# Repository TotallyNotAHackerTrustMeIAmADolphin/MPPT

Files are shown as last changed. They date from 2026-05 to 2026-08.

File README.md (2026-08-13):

# MPPT Controller - STM32F072 Firmware

A professional-grade firmware for a Maximum Power Point Tracking (MPPT) solar charge controller, optimized for the **ARM Cortex-M0** architecture. This project implements high-frequency power conversion with advanced sensing, robust safety, and optimized regulation logic.

---

## 🚀 Key Technical Features

### 1. High-Frequency PWM with Resolution Dithering
- **Frequency:** 200 kHz switching frequency for high power density.
- **Dithering:** Implements a **4-bit dithering table** (16 cycles). This effectively increases the PWM resolution from 240 steps to **3840 steps**, allowing for ultra-fine-grained voltage and current control.
- **Hardware Integration:** Managed via TIM1 with DMA-based automated duty cycle updates.

### 2. High-Performance Sensing (Ping-Pong ADC)
- **Zero-Latency DMA:** Uses circular DMA to sample 6 analog channels continuously.
- **Double Buffering:** Implements industry-standard **Ping-Pong buffering**. The CPU processes one half of the sample buffer while the DMA fills the other half, eliminating data tearing and race conditions.
- **Channels:** Input Voltage, Output Voltage, Input Current, Output Current, MOSFET Temperature, and MCU Internal Temperature.

### 3. Optimized Math Engine (Semantic Fixed-Point)
- **No FPU overhead:** Designed specifically for the STM32F0 (which lacks a hardware Floating Point Unit). All calculations use high-speed 32-bit and 64-bit integer arithmetic.
- **Unit Precision:** 
  - **Voltages:** Millivolts (`_mV`)
  - **Currents:** Milliamps (`_mA`)
  - **Power:** Microwatts (`_uW`)
  - **PWM:** Raw Dithered Ticks (`_ticks`)

### 4. Sunlight-Readable Telemetry Display
- **Hardware:** Integrated **Nokia 5110 (PCD8544)** LCD via SPI1.
- **Performance:** Non-blocking 10Hz UI refresh task decoupled from high-rate power control.
- **UI Design:** Real-time monitoring of Vin, Vout, Pout, and Operation Mode with vertical decimal alignment for high readability.

### 5. Advanced Control & Safety Logic
- **Velocity PI Regulation:** Implements a mathematically stable **Velocity PI algorithm** for Constant Voltage (CV) and Constant Current (CC) modes. This eliminates double-integration instability and provides rock-solid, ripple-free regulation.
- **Limit-Aware MPPT (P&O):** A refined Perturb & Observe algorithm with **power accumulation logic**. It accurately tracks the maximum power point on gentle slopes and intelligently "parks" the duty cycle near user limits to prevent state flapping.
- **Stabilized Global Sweep:** Slowed-down global sweep (15s duration) ensures hardware capacitors settle, providing a near-perfect MPP baseline without voltage offsets.
- **Hardware Safety Architecture:** Dedicated protection layer for the board:
  - **Over-Voltage:** 80V (Vin), 60V (Vout).
  - **Over-Current:** 20A (Input/Output).
  - **Under-Voltage:** 12.5V (Vin) floor to protect auxiliary power.
  - **Thermal:** 85°C internal limit.
  - **Reverse Flow:** Active backflow detection from battery to panel.

---

## 🛠 Hardware & Platform

### Board: openMPPT v1.1 (Custom Architecture)

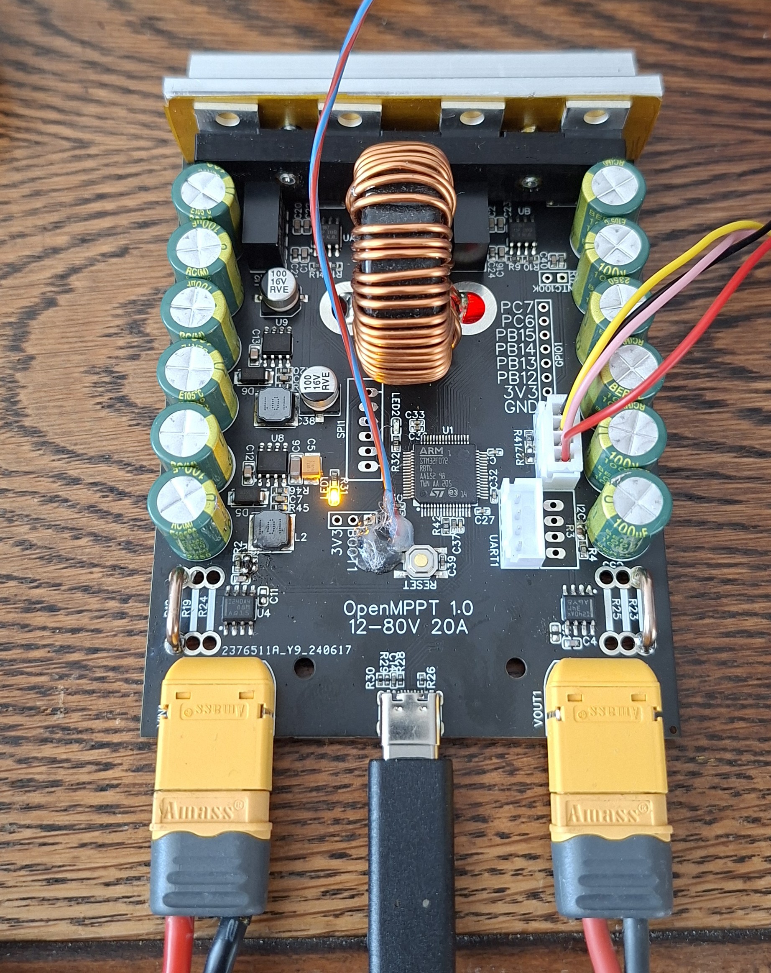
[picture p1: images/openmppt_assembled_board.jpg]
openMPPT assembled board on test bench


- **MCU:** STM32F072RBT6 (ARM Cortex-M0 @ 48MHz).
- **Topology:** 4-Switch Synchronous Non-Inverting Buck-Boost.
- **Power Stage:** Four TI **CSD19505KCS** 80V N-Channel MOSFETs driven by two Infineon **IRS21867STRPBF** gate drivers. High-side drivers are powered by isolated **B1212S-1W** DC-DC converters for continuous high-voltage operation.
- **Sensing:** Precision zero-drift **INA240A4DR** current sense amplifiers. *(Note: Footprints for isolated ACS712 sensors exist as a planned future replacement for the INA240).*
- **Auxiliary Power:** **XL7005A** wide-input buck converters providing 12V and 3.3V logic rails from panel voltage.
- **Display:** Integrated **Nokia 5110 LCD** for real-time telemetry (SPI1).
- **Framework:** STM32Cube HAL.
- **Build System:** PlatformIO using a custom `openmppt` board definition.
- **Headless Operation:** The board regulates autonomously without requiring a serial connection.

---

## 🏗 Build & Development Workflow

### Requirements
- [PlatformIO Core](https://platformio.org/)
- STM32CubeMX (optional, for peripheral reconfiguration)

### Custom Build Automation
This project uses a custom script, `setup_cubemx_env_auto.py`, which bridges the gap between STM32CubeMX and PlatformIO.
- **Automatic Constant Extraction:** The script automatically reads your PWM frequency and timer settings directly from the `MPPT.ioc` file at compile-time.
- **Link Management:** Automatically handles library linking for USB and HAL drivers.

### Commands
```bash
# Build the firmware
pio run

# Upload via Black Magic Probe (standard in platformio.ini)
pio run -t upload

# Open the serial monitor (115200 baud)
pio device monitor
```

## 📈 Auto-Tuning
The firmware supports dynamic parameter tuning over serial. A Python script is provided to automate the finding of optimal MPPT parameters (aggressiveness, step sizes, and filtering) using a hybrid machine-learning approach.

```bash
# Install dependencies
pip install pyserial

# Run the tuner (Phase 1: Random Search, Phase 2: Local Fine-Tuning)
python scripts/tune_mppt.py --port /dev/ttyACM0
```

## 📐 Hardware Design
This repository includes all necessary design files for the MPPT controller hardware in the `hardware/` directory.

- **Schematics:** SVGs and PDFs available in `hardware/schematics/`.
- **PCB Design:** Gerbers, BOM, and Pick-and-Place files located in `hardware/PCB manufacturing/`.
- **3D Files:** STEP file for case/mechanical integration in `hardware/models/`.
- **Project Files:** EasyEDA source files in `hardware/EasyEDA/` and KiCad files in `hardware/KiCad/`.

---

## 🔗 Useful Links & Resources
- **Redirect printf to USB-VCP:** [Alexey Kosinov GitHub](https://github.com/alexeykosinov/Redirect-printf-to-USB-VCP-on-STM32H7-MCU)
- **How to use C++ with STM32 HAL:** [Bare Naked Embedded](https://barenakedembedded.com/how-to-use-cpp-with-stm32-hal/)
- **STM32 ADC Multiple Channels:** [Controllerstech](https://controllerstech.com/stm32-adc-multiple-channels/)
- **Send UART over USB:** [Controllerstech](https://controllerstech.com/send-and-receive-data-to-pc-without-uart-stm32-usb-com/)

---

## 📊 Telemetry & Debugging
Real-time telemetry and configuration are provided via **USB CDC (Virtual COM Port)**.

### 🌐 Web Dashboard
The easiest way to monitor and configure the controller is via the **Web Serial Dashboard**:
👉 **[Live Dashboard](https://totallynotahackertrustmeiamadolphin.github.io/MPPT/)**

*Requires a Chrome or Edge browser. Displays data in standard units (**V**, **A**, **W**) and features a robust settings synchronization mechanism.*

### Serial Protocol
The firmware emits machine-readable **JSON packets** with descriptive fault reporting:
- `Vin_mV / Vout_mV`: Input and Output Voltages.
- `Ain_mA / Aout_mA`: Input and Output Currents.
- `state`: IDLE, SWEEPING, MPPT, CV, CC, FAULT.
- `fault_reason`: Descriptive hardware error (e.g., `INPUT_UNDERVOLTAGE`).
- `duty_x100`: PWM duty cycle as a percentage with 0.01% precision.

---

## 📏 Development Conventions

- **Variable Naming:** Always include the unit suffix in variable names (e.g., `currentIn_mA`).
- **EEPROM Safety:** The board uses a **Signature Check** (`0xABCD`) to ensure safe defaults on first flash. PWM is automatically disabled during Flash writes to prevent controller crashes.
- **Integer Math:** Perform **multiplication before division** in all scaling logic to maintain precision. Avoid `float` and `double` at all costs.

---

## 📝 License
This project is licensed under the MIT License - see the [LICENSE](LICENSE) file for details.

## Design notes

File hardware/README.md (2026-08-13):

# openMPPT Hardware Documentation

## ⚙️ Setup Requirements (per machine)
Before opening `hardware/KiCad/openMPPT_v1.3.kicad_pro`:
- **KiCad 10.0** — matches this project's file format (`generator_version "10.0"`); an older
  major version will prompt to upgrade the files.
- **Install the [`JLCPCB-Kicad-Library`](https://github.com/CDFER/JLCPCB-Kicad-Library) package**
  via KiCad's **Tools → Plugin and Content Manager**. This is the *official* PCM package — don't
  manually download/vendor a copy of it yourself, that's what causes the `KICAD8_3RD_PARTY`
  environment variable to stay unset and 3D models (switches, TVS diodes, generic passives -
  anything from the `PCM_JLCPCB` footprint library) to silently fail to render. Restart KiCad
  after installing so the variable takes effect.
- Everything else (the `easyeda2kicad`-sourced symbols/footprints/3D models for parts not on
  LCSC's basic-parts list) is already vendored in `hardware/KiCad/libraries/` and needs no setup.

## v1.3 Component Selection Summary
| Component | Part Number | Function | Rationale |
| :--- | :--- | :--- | :--- |
| Primary Buck IC | SCT2A25STER | 10V Aux Supply | High efficiency, 100V rating for 80V VIN |
| Logic Buck IC | SY8120B1ABC | 3.3V Logic Supply | Cascaded architecture for MCU safety |
| Power MOSFET | BSC030N08NS5 | Buck-Boost Stage | SMD (PG-TDSON-8-EP), 80V/100A, $R_{DS(on)}$ 3.0mΩ, $Q_g$ 76nC max |
| Bootstrap Diode | US1M | Gate Driver Supply | 1kV rating for transient protection |
| Gate-Off Diode | 1N4148W | MOSFET Turn-off | 4ns high-speed switching for low loss |
| Current Sensor | CC6937S8-3FB020 | Hall Effect Sensing | 3.3V compatible, isolated, 20A range |
| 10V TVS Diode | H12VH22U | Gate Drive Protection | 12V standoff, 6kW surge handled |
| 80V TVS Diode | 5.0SMDJ85CA | Main Rail Protection | 85V standoff, industrial 5kW capacity |

*(See `CALCULATIONS.typ` for full design justification and E24/E96 resistor value derivations.)*

## v1.1 Build Status: SUCCESS (Verified 2026-05-29)
The v1.1 PCB has been fully assembled and verified, v1.1 means the v1.0 but with some patches hand soldered to the board. However, several physical patches are required to achieve full functionality. These must be implemented in the next KiCad revision.

## 🛠 Critical Design Fixes (Implemented in v1.3)
- **Voltage Sensing**: Updated to **200k/4.7k** for 80V range.
- **Current Filter**: C10, C11 removed; moved to isolated **CC6937**.
- **Aux Power**: Replaced XL7005A with **SCT2A25/SY8120** cascaded setup.
- **Connectors**: Standardized on **Male XT60PW-M**.
- **Gate Drive**: Standardized on **5.1Ω** resistors with high-speed **1N4148W** bypass.
- **Protection**: TVS protection on the 80V main rail and 10V gate-drive rail. The 3.3V logic
  rail's originally-planned TVS (H3V3L06B, D9) was removed after datasheet verification showed
  it's an ESD-class part whose own clamping voltage exceeds the STM32's 4.0V absolute max at any
  current beyond a trivial ESD event — no purpose-built power-rail TVS clears 4.0V either (a
  physics limit of 3.3V-class parts). That rail's fault protection now rests on the SY8120B1's
  own regulation and the upstream Vin OV/UV limits already enforced in firmware.

## PCB Design Files
- **KiCad Source**: `hardware/KiCad/`
- **Production Files**: `hardware/PCB manufacturing/`
- **Vendored 3D Models/Symbols/Footprints**: `hardware/KiCad/libraries/easyeda2kicad/` (see
  "Setup Requirements" above for the one library that isn't vendored)

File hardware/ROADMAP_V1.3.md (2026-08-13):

# openMPPT Hardware v1.3 Roadmap

This document outlines the development phases for the openMPPT v1.3 hardware revision. The goal is to evolve the design from the v1.1 baseline into a high-performance, 80V/20A capable, and cost-optimized controller.

## Phase 1: Critical Stability & Bug Fixes
*Goal: Resolve all known hardware issues identified in the v1.1 bench test.*

- [x] **Voltage Sensing Correction**: Change `R1`, `R3` to **200k/4.7k** to enable correct voltage readings up to 80V. [DONE]
- [x] **Connector Standardization**: Use Male `XT60PW-M` on both `VIN` and `VOUT`. [DONE]
- [x] **Robust 10V Gate Drive**: Replace XL7005A with **SCT2A25** tuned to **10V**. [DONE]
- [x] **Cascaded 3.3V Logic Supply**: Implement **SY8120** stepping down from 10V to 3.3V. [DONE]
- [x] **Gate Drive Optimization**: Permanently change gate resistors to **5.1 Ω** with **1N4148W** turn-off diodes. [DONE]
- [ ] **Reset & Debug Pinout**: 
    - Fix the Reset button pinout.
    - Implement **10k Pull-up (SWDIO)**, **10k Pull-down (SWCLK)**, and **47Ω series resistors**.
- [x] **Filter Cleanup**: Recalculated VSense LPF to **3.47 kHz** (10nF). [DONE]

## Phase 2: UI Expansion & Peripheral Headers
*Goal: Formalize the user interface and expansion capabilities.*

- [ ] **Dedicated Nokia 5110 Header**: Standardized 8-pin header (SPI1 + DC/CE/RST + Power).
- [ ] **UI Expansion Header**: 2x Analog (Pots), 3x Digital (Encoder).
- [ ] **SWO Support**: Break out SWO to debug header.

## Phase 3: Power Scaling & Sensor Upgrades (80V/20A)
*Goal: Scale the analog front-end and power stage for higher limits.*

- [x] **Inductor Sizing**: Targeted **33µH - 47µH** with **Isat > 25A**. [SPECS DEFINED]
- [x] **Low-ESR Bulk Capacitance**: Parallel bank of 4x **330µF 100V** (Ymin LKML). [DONE]
- [x] **Hall Effect Current Sensing**: Replaced INA240 with isolated **CC6937**. [DONE]
- [ ] **20A Thermal Design**: 
    - Widen high-power traces.
    - Implement massive thermal via grid for SMD MOSFETs (if used).
- [x] **Overvoltage Protection**: Integrated **5.0SMDJ85CA** (80V) and **H12VH22U** (10V). The
      planned 3.3V TVS (**H3V3L06B**, D9) was removed after datasheet verification found it
      couldn't clear the STM32's 4.0V absolute max at any current beyond a trivial ESD event —
      see `CALCULATIONS.typ`. That rail's protection now rests on the SY8120B1's own regulation
      plus the upstream Vin OV/UV limits. [DONE]

## Phase 4: Architectural Optimization & Cost Reduction
- [x] **SMD Migration**: Transition to **BSC030N08NS5** or keeping **BRCS030N10SHRA** (TO-220) based on board space.
- [ ] **Unified Dev Header**: Combined Reset, UART, and SWD.
- [x] **Switching Frequency: 200kHz**: `TIMER_PERIOD` (`system_config.h`/`MPPT.ioc`) has
      actually computed to 200kHz since the earliest commit in this repo's history — this
      was previously undocumented, not a pending change. Component re-check done — see
      `CALCULATIONS.typ` Section 8: MOSFET switching loss roughly doubles vs. a
      hypothetical 100kHz (thermal design from this phase must land first/alongside), gate
      driver has ample margin, main inductor target halves to ~25uH. What genuinely *was*
      missing until the bootstrap-refresh firmware update: `DITHER_TABLE_SIZE` was never
      paired with the halved period (8→16 fix), and the PWM hardware map needed a
      bootstrap-cap-safe rework for v1.3's bootstrap-cap gate drive (no isolated supply).

## Phase 5: Verification & Manufacturing
- [ ] **Full DRC/ERC Audit**: Zero errors in KiCad using `kicad-cli`.
- [ ] **BOM Scrubbing**: Final LCSC part verification.
- [ ] **Generation of Production Files**: Gerbers, Drill, BOM, and CPL.

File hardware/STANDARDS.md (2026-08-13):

# openMPPT Hardware Engineering Standards

## Project Overview
This directory contains the KiCad electronic design files for the openMPPT controller.

## Core Mandates
- **Safety First**: High-power traces (VIN, VOUT, GND, VS_A, VS_B) must be sized for 20A continuous load. Standard width is **3.5mm** (assumes 2oz copper or dual-side reinforcement).
- **Component Selection**: Prioritize the **PCM-JLCPCB** library for preferred parts whenever possible.
- **Persistent Memory (Hardware Universe)**: Every new component mapping or pinout MUST be persisted into the **Hardware Universe** section immediately.
- **Mandatory Audits**: No changes shall be merged into `main` without a clean DRC/ERC report.

# Hardware Universe (Source of Truth)

## 1. MCU Pin Mapping (STM32F072RBT6)
| MCU Pin | Signal | Function | Resistors |
| :--- | :--- | :--- | :--- |
| PA13 | SWDIO | Debug Data | 10k Pull-up, 47Ω Series |
| PA14 | SWCLK | Debug Clock | 10k Pull-down, 47Ω Series |
| BOOT0 | BOOT0 | Boot Mode | 10k Pull-down |
| PC10 | LED | Heartbeat | Active-Low |

## 2. Power Stage Components (v1.3 Finalized)
| Ref | Part Number | Function | LCSC # |
| :--- | :--- | :--- | :--- |
| Q1-Q4 | **BSC030N08NS5** | Power MOSFETs | C501507 |
| U1 | **STM32F072RBT6** | MCU | C46046 |
| UA1/UB1 | **IRS21867STRPBF** | Half-Bridge Gate Driver | C52290 |
| U2/U3 | **CC6937S8-3FB020** | Isolated Current Sensor | C41421919 |
| U4 | **SCT2A25STER** | 10V Primary Aux Buck | C5124114 |
| U5 | **SY8120B1ABC** | 3.3V Logic Buck | C88474 |
| L4 | **HCZH-3218-150-M** | Buck-Boost Stage Inductor | C53699952 |
| L2 | **GXDR1207-470MT** | Aux Supply Inductor (SCT2A25/10V) | C52196367 |
| L3 | **FTC201610S4R7MBCA** | Aux Supply Inductor | C5832346 |
| C15-C18,C20-C23 | **LKML2502A331MF** | 330uF Bulk Electrolytic Cap | C443153 |
| C_IN1/C_IN2 | **TCC1210X7R225K101MT** | Input Filter Cap | C5449052 |
| D10/D11 | **5.0SMDJ85CA** | 80V Bus Protection | C42394457 |
| D8 | **H12VH22U** | 10V Gate protection | C20615799 |
| D1/D4 | **SS210** | Gate Driver Bootstrap Diode | C14996 |
| D2/D3/D5/D6 | **SS210** | Gate Discharge Diode | C14996 |
| D7 | **SS510** | Aux Buck (SCT2A25) Catch Diode | C18199171 |
| GPIO1/SPI-I2C1 | **2541WV-08P** | 8-pin Header (GPIO/SPI/I2C) | C5383116 |
| ST_LINK1/UART1 | **B4B-XH-A** | 4-pin JST-XH (ST-Link/UART) | C144395 |
| NTC1 | **PZ254V-11-02P** | 2-pin Header (NTC) | C492401 |
| H2 | **PZ254V-11-04P** | 4-pin Header | C2691448 |
| USB1 | **TYPE-C16PIN2MD** | USB-C Connector | C2765186 |
| VIN1/VOUT1 | **XT60PW-M** | Power Connector (In/Out) | C98732 |

> **L4 changed from `FC-SE2822-150M` to `HCZH-3218-150-M`** (YOUCHI, LCSC `C53699952`,
> $3.86, 88 in stock) — applied to `buck_boost.kicad_sch`, *not yet applied to the PCB*
> (its footprint uses a different pad shape/format than what's currently placed, so it
> needs a deliberate footprint swap in KiCad, not a drop-in text edit).
>
> Same 15uH as the original part, so the ripple picture is unchanged: clears the
> <100mV target at the firmware's actual 200kHz operating point (78mV) but would not
> clear it at a hypothetical 100kHz (157mV) — L4 was deliberately sized against the real
> 200kHz operating point (`TIMER_PERIOD=240` has computed to 200kHz since the earliest
> commit in this repo's history, confirmed via git log, not merely assumed). What changed
> is DCR (3.5mOhm -> 2.2mOhm, cutting conduction loss from 1.40W to 0.88W) for a $1.56
> premium over the original part.
>
> This was chosen over several alternatives considered along the way (see
> `CALCULATIONS.typ` Section 8 for the full comparison): the absolute cheapest option
> was the original part itself ($2.30); a same-inductance/near-free upgrade
> (`C54830921`, +$0.57, 89% Isat margin) was available; and a higher-margin option
> (`RSEQ32-220M`/`C37634008`, $6.26, 22uH, 304% Isat margin, 0.36W conduction loss) was
> evaluated and rejected as solving for more margin than the design needs, at a stock
> and price cost that didn't justify it for a prototype build.

> **L2 changed from `APS0650M470A` to `GXDR1207-470MT`** (FAUKU, LCSC `C52196367`,
> $0.207, 11735 in stock) — applied to both `power.kicad_sch` and the PCB. Same 47uH,
> but Isat goes from 2.62A to 4.0A, now matching `SCT2A25STER`'s own 4A peak current
> limit instead of saturating well below it, and DCR drops from 227mOhm to 90mOhm.
> Driven by a hypothetical heavier load (e.g. a fan) beyond the gate-driver/logic load
> the rail was originally sized for. Package grew from 7.7x6.6mm to 12.5x12.5mm SMD.

> **Why SS210 for both D1/D4 (bootstrap) and D2/D3/D5/D6 (gate discharge)**: D2/D3/D5/D6
> only ever see the ~10V gate-drive swing, so SS210's 100V/2A rating is more margin than
> that role strictly needs — a smaller Schottky (e.g. `B5819W`, 40V/1A, same `D_SOD-123`
> footprint already placed at those 4 spots) would be a tighter fit. Deliberately not
> doing that: one diode part number across all six positions beats a marginally-better
> fit on four of them — fewer reels at assembly, less inventory, less chance of a mix-up
> during hand work. SS210 comfortably meets every requirement of both roles (voltage,
> surge current, Schottky switching speed), just with headroom to spare on the discharge
> role.

> **D2/D3/D5/D6 footprint fixed, placement still pending**: these previously had
> `D_SOD-123` footprints on the PCB despite the schematic (correctly) specifying
> `D_SMA` for all six SS210s — now corrected to `D_SMA`, with pad-net mapping/polarity
> preserved. Since the board isn't routed yet, this surfaced the expected next step:
> `D_SOD-123` (~2.7x1.6mm) is much smaller than `D_SMA` (~5x2.6mm), so D2/D3/D5/D6
> need to be spread apart from each other and from nearby parts (R9, R10, R17, R18,
> R36-R39, UA1, UB1) during placement — normal pre-routing layout work, not a bug.

## 3. Tooling
- **KiCad CLI**: `C:\Program Files\KiCad\10.0\bin\kicad-cli.exe`
- **Vendored Library**: `hardware\KiCad\libraries\easyeda2kicad\` (16 parts not available via PCM — symbols/footprints/3D models fetched with the `easyeda2kicad` tool, registered in `sym-lib-table`/`fp-lib-table`).
- **JLCPCB Passives**: install the `CDFER/JLCPCB-Kicad-Library` package per-machine via KiCad's Plugin & Content Manager — not vendored into the repo.
- **Component swap script**: `hardware/scripts/swap_part.py` — vendors a new LCSC part and swaps it into a schematic (and optionally the PCB), handling the reformatting/UUID/net-preservation details that are easy to get wrong by hand (and have been, repeatedly). Doesn't touch STANDARDS.md/CALCULATIONS.typ or run ERC/DRC — update the docs and open KiCad to check the result yourself, same as always. See the script's own docstring for usage and its current limitations (simple passives/2-terminal parts, legacy `module`-format footprints only).

## 4. Working with Claude

Claude reads/edits the KiCad project as plain text (`.kicad_sch`/`.kicad_pcb` are S-expression
files) — it cannot open KiCad's GUI or judge layout/routing visually without a screenshot.
Workflow:

- **Visual review**: paste a screenshot of a schematic sheet, PCB layout, or 3D view. Claude
  cross-checks what's visible against this Hardware Universe table and `CALCULATIONS.typ`, and
  reads the underlying `.kicad_sch`/`.kicad_pcb` for anything a screenshot can't show precisely
  (exact net names, trace widths, footprint bindings).
- **Anti-staleness check**: before a hardware PR, or on request, Claude greps every reference
  designator in the Hardware Universe table against the actual KiCad files and reports any drift
  in footprint/value/net, rather than trusting the table from memory. Keep this table limited to
  what's genuinely hard to derive from the files (rationale, "why this part") — the KiCad project
  itself is the source of truth for raw pin/footprint data.
- **Part selection & calculations**: for new components, Claude checks datasheet specs against
  the operating envelope (MOSFET Vds/Rds(on)/Qg vs. 200kHz switching losses, inductor Isat/DCR vs.
  the 20A continuous rating, TVS clamping voltage vs. the 80V rail margin, sensor bandwidth vs. the
  ~1.5kHz control loop), checks LCSC/JLCPCB stock/package availability, and documents the
  derivation in `CALCULATIONS.typ` — not just the final part number.
- **DRC/ERC enforcement**: this is a people job. Claude does not run `kicad-cli` DRC/ERC, proactively
  or on request — board correctness review stays with the user. The "no merge without a clean
  report" mandate above is checked by the user, not by Claude.
- **Change mechanics**: hardware edits (this file, `CALCULATIONS.typ`, KiCad files) go through a
  `hardware/<name>` branch and PR, per `CLAUDE.md` — never committed straight to `main`. Example:
  `hardware/fix-resistor-values`.

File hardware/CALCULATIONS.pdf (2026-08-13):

# openMPPT Hardware Design Calculations

Theoretical basis and calculations for component selection

## 1. Power Stage Parameters

Parameter | Symbol | Value | Notes
Switching Frequency | fsw | 200 kHz | TIMER_PERIOD = 240 in system_config.h/ MPPT.ioc — confirmed via git history to have been the standing config for a year, not a future change
Maximum Input Voltage | Vin,max | 80 V | Hardware limit
Maximum Output Current | Iout,max | 20 A | Safety limit
Nominal System Voltage | Vsys | 12V / 24V / 48V | Target batteries
Gate Drive Voltage | Vdrive | 10 V | Optimized for IRS21867 thermals (v1.3)

200kHz is the actual, standing firmware config — not a planned migration. TIMER_PERIOD = 240 has computed to 200kHz since the earliest commit in this repo’s history; this was previously undocumented and this table incorrectly described it as a future 100kHz→200kHz change. What genuinely was outstanding until this PR: the PWM dither table (DITHER_TABLE_SIZE) was never paired with the halved period, so the firmware was silently running at half the duty-cycle resolution 200kHz should have — fixed by bumping DITHER_TABLE_SIZE 8→16 alongside a bootstrap-cap-safe PWM map for v1.3 (no isolated gate supply). See Section 10 for the full component re-check.

## 2. Gate Drive & Auxiliary Power Optimization (v1.3)

Primary Aux Supply (10V) - SCT2A25: Replaces the unstable 12V XL7005A with a robust 100V-rated step-down (SCT2A25).
- Output is tuned to 10V instead of 12V.
- Feedback Divider: VFB = 1.2V
- VOUT = 1.2 × (1 +
Rup

Rdown)

- Using E96 series: Rup = 110 kΩ, Rdown = 15 kΩ → VOUT = 1.2 × (1 +

110/15) = 10.0V
- Switching Frequency: Fixed at 300kHz.
- Inductor (L1
): For 10V out, a standard 33µH or 47µH inductor (e.g., 6x6mm shielded) is suitable.
- UVLO Divider: To set start at 12.5V: RUVLO_TOP = 430 kΩ, RUVLO_BOT = 47 kΩ (Both are E24).
- SW-node Freewheeling Diode: D7, SS510 (100V, 5A Schottky, C18199171) between the switch node and GND. (Previously documented here as “US1M” — never actually placed; verified against the schematic’s real net connections.)

Secondary Aux Supply (3.3V Logic) - SY8120:
- Uses a “Cascaded Buck” architecture: 10V → Tiny Sync Buck (SY8120) → 3.3V.
- Feedback Divider: VFB = 0.6V
- VOUT = 0.6 × (1 +
Rup

Rdown)

- Using E24 series: Rup = 68 kΩ, Rdown = 15 kΩ → VOUT = 0.6 × (1 +

68/15) = 3.32V ≈ 3.3V
- Switching Frequency: Fixed at 500kHz.
- Inductor (L): 4.7µH (recommended for 3.3V out).

Aux power chain verified against datasheets. SCT2A25STER: input range 5.5-100V (20V headroom over the 80V bus, comfortable margin below the 12.5V min startup voltage), VFB =1.2V±2% confirmed (validates the 110kΩ/15kΩ divider math above), 2A continuous/4A peak output vs. an estimated 150-500mA actual load (gate driver quiescent + switching current + SY8120′s input-referred draw) — current isn’t the sizing constraint, voltage range is. It’s an asynchronous buck (only the high-side switch is integrated), which is why D7 (the freewheeling diode above) is required, not optional. Datasheet is marked “Preliminary Specification, Rev.0.8” by the manufacturer — worth knowing this is pre-release.

SY8120B1ABC: verified against the actual SY8120B1 datasheet (matching LCSC C88474 exactly — the SY8120E1ABC datasheet used earlier was a same-family but different order-code stand-in, since superseded). VFB=0.6V confirmed (validates the 68kΩ/15kΩ divider math above). Input range 4.5-18V vs. the 10V it actually sees (fed from SCT2A25′s output, not the 80V bus directly) — good margin both directions. Top FET current limit (ILIM,TOP) is 2-3.6A, comfortably above L3′s 2A Isat — same category of fault-current gap as L2 had, but not upgraded: the 3.3V rail only realistically feeds the MCU/logic, nowhere near saturating L3 even with headroom for extras, unlike L2′s fan-load scenario. Decision, not an oversight.

Why D7 stays SS510, not consolidated to SS210 (unlike D1-D6, see STANDARDS.md): SCT2A25′s own 4A peak current limit exceeds SS210′s 2A continuous rating — under fault/ inrush/heavy-transient conditions the diode could see close to that 4A, which would overstress SS210 but not SS510 (5A rated). D1-D6 avoided this problem because their worst-case stress is nanosecond-scale gate-charge pulses, not sustained fault current a diode has to survive thermally.

L2 changed for the same reason D7 stays SS510: the original APS0650M470A (47µH, Isat 2.62A, DCR 227mΩ) saturates well below SCT2A25′s 4A peak limit — fine for the 150-500mA baseline load, not fine if a heavier load (e.g. a fan) gets added to the 10V rail. Replaced with GXDR1207-470MT (FAUKU, C52196367, $0.207, 11735 in stock): same 47µH, Isat 4.0A (now matching the IC’s own peak limit exactly instead of saturating below it), DCR 90mΩ (vs. 227mΩ — meaningfully lower conduction loss regardless of actual load). Package grew from 7.7×6.6mm to 12.5×12.5mm SMD.

3. Gate Driver / MOSFET Drive Synergy (IRS21867STRPBF,

## R36-R39, R9/R10/R17/R18)

Verified against the Infineon IRS21867S datasheet (full electrical table, not just the summary timing specs already checked in Section 10).

- Supply range: 6.8-20V vs. the 10V design point — comfortably mid-range, not a marginal operating point, so the propagation-delay specs (characterized at 15V) should hold closely at 10V too.
- Driver output current: IO+ (source) 5.34-6.66A, IO- (sink) 4.90-6.10A typ/max — higher than the “4.0A typ” headline spec. With 10V drive through the 2.2Ω gate resistor (R36-R39), resistor-limited peak current is 10

V
2.2Ω ≈ 4.55A — below the driver’s 5.5-6A capability, meaning the resistor is deliberately the dominant current limiter (predictable dV/dt/EMI), not the driver’s raw max rating.
- Switching speed: gate charge time ≈20-25ns (76nC max Qg
, current tapering from 4.55A toward 2.45A through the Miller plateau at Vplateau ≈ 4.6V). Combined with the driver’s 170-250ns propagation delay, total turn-on latency ≈200-275ns — about 4-5.5% of the 5000ns period at 200kHz, comfortable margin for dead-time budgeting.
- 100kΩ gate pulldown (R9/R10/R17/R18): the driver’s own UVLO drives HO/LO low when VCC/VBS is present-but-insufficient, but can’t do anything with zero power (e.g. before the 10V rail comes up during power-on sequencing) — that’s the specific gap this resistor covers. Negligible power draw during normal operation (100µA @ 10V); not intended for Miller-transient immunity during real switching (the driver’s actively-low output handles that), just a defined off-state before the driver is powered. Sane, standard value for that job.

## 4. Transient Voltage Suppression (TVS) Strategy

Primary Bus Protection (80V):
- Component: 5.0SMDJ85CA (Bidirectional, 5kW). Verified against the Hongjiacheng 5.0SMDJ series datasheet, 85V row: VRWM=85V, VBR=94.4-104V min/max, VC=137V @ IPP=36.5A (the exact 5000W spec point: 137V times 36.5A approx 5000W). Part number carries the CA suffix, which the datasheet’s own numbering note defines as bidirectional - matches the “Bidirectional” call here, though the schematic’s library symbol is filed as TVS-Uni,5.0SMDJ85CA (worth confirming in KiCad that the symbol’s polarity graphic doesn’t visually mislead a schematic reader).
- Rationale: Standoff (VRWM) of 85V ensures no leakage at 80V (IR only 5µA at VRWM, confirmed). The 5000W/10-1000µs rating (a lightning-surge waveform, appropriate for externally-coupled solar/connector transients) lets it absorb genuine surge energy without self-destructing.
- Known limitation, not a defect: this TVS cannot clamp the bus below the main MOSFETs’ rating. BSC030N08NS5′s own datasheet lists VDS absolute max as exactly 80V - zero headroom above the system’s own 80V bus limit - while this TVS’s breakdown floor is 94.4V minimum, by construction (it has to sit above the 85V standoff to avoid nuisance conduction at normal bus voltage, same underlying reason any TVS needs separation from its own breakdown voltage). No TVS standing off near 85V could protect a MOSFET with zero voltage margin; that’s a MOSFET voltage-margin decision (e.g. a 100V-rated part), not something this component can fix. This TVS’s real job is preventing catastrophic board failure (fire, ruptured caps) from an external surge
- not guaranteeing the MOSFETs stay in-spec during one.
- Placement: Immediately adjacent to VIN/VOUT XT60 connectors.

Gate Drive Protection (10V):
- Component: H12VH22U (6kW Surge). Verified against its datasheet: VRWM=12V (20% headroom over the 10V rail, IR=1µA at VRWM - confirmed low-leakage), PPP=6000W / IPP=210A at 8/20µs (matches the “6kW Surge” call), clamping voltage 13-15V @ 20A pulse -comfortably under the IRS21867′s 25V absolute max. Only exceeds that (30V) at the extreme edge of its own 200A rating, far beyond anything this rail could realistically deliver (the SCT2A25 aux buck feeding it is already current-limited to 4A, per the earlier gate-driver verification). Unlike D9′s H3V3L06B, this is a genuine surge-capable part (DFN2020-3L, 75x the pulse power), not a phone-ESD chip-scale device wearing a similar part-family name - no changes needed.
- Rationale: 12V standoff ensures invisibility at 10V rail. Protects sensitive IRS21867 drivers (25V max) from regulator failure.

Logic Protection (3.3V): removed (v1.3), D9 deleted.
- Previously H3V3L06B. Datasheet verification found it’s an ESD-class part (DFN0603-2L, IEC 61000-4-2 rated, 80W / 8A pulse rating) rather than a power-rail transient absorber, and its own clamping-voltage table (3.5-6V at 1A, up to 10V at its rated 8A) exceeds the STM32′s 4.0V absolute max (confirmed against the STM32F072 datasheet, Table 21: Voltage characteristics) at any current beyond a trivial ESD-level event - it could not do the job its own rationale claimed.
- Checked purpose-built power-rail TVS alternatives before removing it: Nexperia PTVS3V3S1UR (400W) clamps at 8V, Littelfuse SMF3.3 (200-1200W) clamps at 6.8V. Neither clears 4.0V either -this is a physics limit of 3.3V-class TVS diodes (they need real separation from their own breakdown voltage to keep leakage low at rest), not a part-selection mistake. No drop-in replacement exists that actually satisfies the original “keeps the rail under 4.0V” rationale.
- Decision: remove D9 rather than keep a component that can’t do its stated job. The 3.3V rail’s fault protection now rests on the SY8120B1′s own regulation and the upstream Vin OV/UV limits already enforced in system_config.h, not an additional clamp on this rail.

## 5. Inductor Sizing (Main Power Stage)

Targeting a peak-to-peak ripple current (ΔIL) of 20% of Iout,max (4.0 A).

Buck Mode Worst-Case: (50% Duty Cycle, e.g., 80V in, 40V out)

Lbuck =

Vout × (Vin − Vout)
ΔIL × fsw × Vin

At fsw = 100kHz: Lbuck =

40×40
4.0×100000×80 = ∗ 50.0µH ∗

v1.3 Component Selection: Target inductor size: 33 µH to 47 µH.
- CRITICAL: Saturation Current (Isat) MUST be > 25A. Using a lower Isat (like 11A) will cause magnetic collapse and MOSFET destruction.

## 6. Bulk Capacitor Selection

Targeting an output voltage ripple (ΔVout) of < 100mV.

ESRmax =

ΔVout
ΔIL

=

0.1V
4.0A

= ∗ 25mΩ ∗

v1.3 Capacitor Strategy:
- Use 4x 330µF 100V Low-ESR Electrolytic (Ymin LKML2502A331MF, C443153) in parallel, per bulk bank (input and output each get their own 4-cap bank, C15-C18 / C20-C23 in the schematic).
- Verified against the Ymin LKM series datasheet (not assumed): the part number itself decodes to series LKM + diameter code L (12.5mm) + height code 250 (25mm) + voltage code 2A (100V) + capacitance code 331 (330µF) + M (±20%) - exactly LKML2502A331MF. The series’ standard-item table confirms the 12.5×25mm/100V/330µF row directly: ESR = 47mΩ max and ripple current = 2.14A rms, both specified at 100kHz/25°C - the exact figures this section already assumed.
- Total Bank ESR: 47mΩ
4 = ∗ 11.75mΩ ∗ (Passes the 25mΩ limit with 53% margin).
- Total Ripple Capacity: 2.14 A × 4 = ∗ 8.56 A ∗ per bank. The actual RMS ripple current a bulk cap bank sees is ≈

ΔIL
2

√
3

≈ 1.15 A - the 8.56A rating is headroom against that, not a comparison to the 20A DC bus current.
- Voltage margin: 100V rating on an 80V max bus is a 20% derating margin - inside the range electrolytics are normally run at continuously, though tighter than the 25-30% some DC-link guidance recommends.
- The series’ own ripple-current frequency correction table (0.40, 0.50, 0.80, 0.90, 1.00 at 50Hz, 120Hz, 1kHz, 10-50kHz, 100kHz respectively) confirms the rated ripple current is already anchored at its ceiling by 100kHz, with no published derating beyond that - supporting the “frequency-independent” call in the Section 10 re-check below.
- Cost pass (checked, not adopted): cheaper and SMD alternatives were surveyed against this same spec. Nothing beats LKML2502A331MF on cost, ESR, ripple, and life simultaneously - every cheaper part found trades away life rating (10000h to 5000h) to hit its price point. The one genuine free improvement: 3 caps per bank would already suffice -

47mΩ
3 ≈ 15.7mΩ still clears
the 25mΩ limit with 37% margin, and ripple capacity (2.14 A × 3 ≈ 6.4 A) stays far above the 1.15A actual RMS need. Staying at 4x for the extra ESR/ ripple headroom and to keep it symmetric with the input/output bank layout - not a requirement, a margin choice.

## 7. Voltage Divider & ADC Scaling

Voltage Sensing LPF (v1.3 Optimized):
- Rtop = 200 kΩ, Rbottom = 4.7 kΩ.
- Rth ≈ 4.59 kΩ
- Cfilter = 10 nF

- fc =
2π×4590×10×10

−9 ≈ 3.47 kHz
- Evaluation: Balanced for high-speed tracking and noise rejection.

## 8. Current Sense (CC6937S8-3FB020, U2/U3)

Verified against the CrossChip CC6937 datasheet (not a name-convention guess).

- Type: Isolated Hall Effect, 3750VRMS isolation (pins 1-4 to 5-8) — 47x margin over the 80V bus.
- Sensitivity: 66mV/A (confirmed from the ordering table for the −3FB020 variant).
- Supply: VCC 3.0-3.3V nominal — the “3” in “3FB” denotes the 3.3V-supply series, matching the system’s logic rail exactly.
- Range: ±20A. Zero-current output VOUTQ ≈ 1.65V (VCC/2, confirmed), full scale swings to ≈ 0.33-2.97V — centered and within a 3.3V ADC’s linear range.
- Response time: 1.5µs (10-90% step) — well under one 200kHz switching period (5µs), adequate for fast overcurrent/backflow trip.
- Bandwidth: 230kHz −3dB, 150x margin over the 1.5kHz control loop sample rate. Margin over switching frequency shrinks from 2.3x (100kHz) to 1.15x (200kHz) at full power — not a concern for this design (average sensing + fast-trip response time, not raw bandwidth, govern both use cases here), but worth knowing if the sensor’s role ever changes to reconstructing switching-ripple waveforms directly.
- Insertion loss: 0.5mΩ internal conductor resistance — negligible, and the reason this replaced the INA240+shunt approach from v1.1 (per ROADMAP_V1.3.md).
- Decoupling: 1nF VREF-to-GND (matches the datasheet’s own CREF=1nF test condition; confirmed in the schematic as C10/C26) and a separate 100nF (0.1µF) VCC bypass (confirmed as C12 near U2). Also 1nF at VOUT per the datasheet’s COUT=1nF condition.

## 9. Factory Calibration Defaults (settings.c)

Calibration_t needs sane defaults so a fresh board reads roughly-correct values before real calibration is run (per the EEPROM signature-check pattern in CLAUDE.md). Derived from the hardware specs above, not bench-measured — replaces stale v1.1-era defaults that were still assuming the pre-v1.3 divider ratio ( 3.3x off from the actual 200k/4.7k parts).

Voltage (Vin/Vout share identical R5/R6 and R13/R14 200k/4.7k dividers):

raw = Vreal,mV ×

4.7
204.7

÷ 3300mV × 4096

(12-bit ADC, VDDA ≈ 3300mV.) Gives 285 @ 10V, 855 @ 30V — used as the Low/High calibration pair for both channels.

Current (Iin/Iout share identical CC6937S8-3FB020, 66mV/A, VOUTQ = VCC/2 = 1.65V @ 0A):

raw = Vadc,mV ÷ 3300mV × 4096

Gives 2048 @ 0A exactly (the datasheet’s own zero-current condition) - this point is polarity-independent, always correct regardless of sign. The 10A high point (1229 raw) assumes higher current reads as a lower raw value, matching the slope direction of the previous (bench-measured, v1.1-era) defaults for this field - not independently verified against the physical board. The polarity depends on which way current actually flows through U2/U3 relative to their pin 1-4/5-8 orientation, which isn’t something derivable from the datasheet alone. Bench-verify the sign before trusting these current defaults in the field; if it’s backwards, the fix is recomputing the high point with the opposite sign (2048 + 10000×0.066/3300×4096 ≈ 2867 instead of 2048 − … ≈ 1229) - not simply swapping the two existing numbers, which would produce a different wrong pair, not the correct one.

## 10. 200kHz Operation: Component Verification

This section verifies the selected parts against the switching frequency the firmware actually runs at (200kHz, confirmed via git history — not a future migration), using values pulled directly from the vendored datasheets (not assumed). Comparisons against 100kHz are kept below for reference/ context, not because 100kHz is a live alternative. This is the check called for by the STANDARDS.md “Part selection & calculations” mandate for the ROADMAP_V1.3.md Phase 4 checklist item.

### 10.1. Main Switching MOSFETs (Q1-Q4, BSC030N08NS5, C501507)

Source: Infineon BSC030N08NS5 datasheet, Rev. 2.3, 2019-10-31.

Parameter | Value | Condition
RDS(on) | 2.6 mΩ typ / 3.0 mΩ max | VGS=10V, ID=50A
Qg (total gate charge) | 61 nC typ / 76 nC max | VDD=40V, ID=50A, VGS=0→10V
tr (turn-on rise) | 12 ns typ | VDD=40V, VGS=10V, ID=50A, RG,ext =3Ω
tf (turn-off fall) | 13 ns typ | same
Coss | 700 pF typ / 910 pF max | VDS=40V, f=1MHz
Rth JA (PCB only, no heatsink) | 50 K/W | 6 cm² copper, 1-layer, natural convection
Tj,max | 150 °C | —

Conduction loss (frequency-independent):

Pcond = I

2
rms × RDS(on),max = 20

2 × 0.0030 ≈ ∗ 1.2 W ∗

Switching loss (linear-approximation model, worst case VDS = 80V, ID = 20A):

Psw =

1
2

× VDS × ID × (tr + tf

) × fsw

| 100 kHz (reference only) | 200 kHz (actual)
Psw per hard-switched MOSFET | 2.0 W | 4.0 W
Pcond per MOSFET | 1.2 W | 1.2 W (unchanged)
Total est. loss | ≈3.2 W | ≈5.2 W

Thermal flag — live at the firmware’s actual 200kHz, not hypothetical. With PCB-only cooling (Rth JA=50 K/W, no heatsink/thermal vias), the datasheet’s own max package dissipation at TA=25°C is Ptot =

150−25
50 = ∗ 2.5 W ∗ — already below the ≈3.2W estimate at 100kHz, let alone the ≈5.2W the board actually sees at its real 200kHz operating point. This assumes worst-case VDS/ID coincidence and a simplified switching-loss model (real loss depends on which of Q1-Q4 is hard-switched vs. synchronous-rectifying in the actual buck-boost topology, and gate resistance/drive strength affect tr/tf
| in-circuit). This is exactly what ROADMAP_V1.3.md
Phase 3′s open item (“20A Thermal Design: widen high-power traces, implement massive thermal via grid”) already anticipates — that item should land before or alongside the 200kHz switch, not after. The bottom-side Rth JC path (0.5-0.9 K/W typ/max) is dramatically better than the PCB-only path and is what a proper thermal via array would unlock.

Gate drive loss (in the driver/gate resistor, not the MOSFET junction — informational):

Pgate = Qg × VGS × fsw = 76 × 10

| −9 × 10 × fsw

At 100kHz: 76mW/MOSFET. At 200kHz: 152mW/MOSFET. Not a concern for the driver IC’s thermal budget either way.

Cost pass (checked, not adopted): a cheaper 100V candidate, Huixin H80N10FB (C49823472), was evaluated to replace BSC030N08NS5 - similar RDS(on) (3.0/3.6mΩ) and Qg
(67/100.5nC) made it look
like a clean upgrade at first pass. It was not adopted: its datasheet lists tr=92.0ns / tf=82.4ns typ (comparable test conditions to the table above) - 6-7x slower than BSC030N08NS5′s 12/13ns, despite the similar Qg

. Re-running the switching-loss formula above with those numbers gives ≈ 14 W per MOSFET at 100kHz alone (vs. the 2.5W PCB-only thermal ceiling this section already flags), instead of the expected 2.0W. Lesson for future MOSFET swaps on this board: RDS(on) and Qg alone don’t predict switching speed - Qg
is gate charge, not switching time, and depends heavily on a part’s internal gate resistance and Miller-plateau behavior. Always check tr/tf

(or td(on)/td(off))
against a comparable test condition before treating a swap as electrically equivalent.

### 10.2. Gate Driver (IRS21867STRPBF, C52290)

Source: Infineon IRS21867S datasheet v01.00.

Parameter | Value | Condition
ton / toff propagation delay | 170 ns typ / 250 ns max | VCC = VBS=15V, CL=1000pF
MT (delay matching, |ton − toff|) | 35 ns max | —
tr / tf (driver output) | 22/18 ns typ, 38/30 ns max | —
Output source/sink current | 4.0 A typ | —

At 200kHz the switching period is 5.0µs vs. 10µs at 100kHz. The 170-250ns propagation delay grows from 2.5% to 5% of the period — worth including explicitly in dead-time budgeting, but well within normal margins; not a hard blocker on 200kHz operation. Output drive current (4.0A) is unchanged and still comfortably swings Qg=76nC in the tens-of-ns range required. No datasheet-stated
maximum switching frequency applies here.

### 10.3. Main Inductor (L4)

Re-deriving Section 5′s formula at 200kHz:

Lbuck(200kHz) =

40 × 40
4.0 × 200000 × 80

= ∗ 25.0µH ∗

This halves the 100kHz target (50µH → 25µH). The originally-placed part, FC-SE2822-150M (C46553544, verified via datasheet, not the name-convention guess this section originally used): 15µH ±20%, Isat 30.5A, rated 30A, DCR 3.5mΩ, 28x23mm THT, $2.30 / 407 in stock.

| 100kHz (reference only) | 200kHz (actual firmware)
Ripple current ΔIL | 13.3A | 6.67A
Peak current / Isat margin | 26.7A / 14% | 23.3A / 31%
Output ripple ΔVout (bank ESR 11.75mΩ) | 157mV — 57% over the 100mV target | 78mV ✓
Conduction loss (I out × DCR) 2 | 1.40W | 1.40W (freq-independent)

L4 only meets the ripple spec at 200kHz — a real, accepted dependency, not a bug. It was deliberately sized against the firmware’s actual 200kHz operating point (confirmed via git history, not merely assumed), specifically to avoid the “humongous” 50µH part a 100kHz target would otherwise require. This is not something to fix by re-checking values; it’s a documented design decision.

Candidate replacements evaluated — two rounds. First pass (22-30µH / Isat≥30A, filtered to in-stock — 19 of 21 candidates found were out of stock and excluded) optimized purely for margin and found C37634008 (RSEQ32-220M, Ruishen): 22µH, Isat 90A, DCR 0.9mΩ, $6.26/26 in stock — 304% Isat margin and 0.36W conduction loss at 200kHz, a huge improvement. Rejected after a second look: this compared candidates against each other without ever checking the original part’s own price/stock ($2.30, 407 in stock) — a 2.7x price and 15x stock gap that makes “maximum margin” the wrong optimization target for a prototype build.

Second pass widened the inductance range (15-33µH) and weighed cost/stock properly:

FC-SE2822-150M (orig.) | C54830921 | HCZH-3218-150-M (chosen) | C37634008
Manufacturer FANGCHENG | Coilank | YOUCHI | Ruishen
Stock / 407 / $2.30 Price | 69 / $2.87 | 88 / $3.86 | 26 / $6.26
L / 15µH / 30.5A / 3.5mΩ Isat / DCR | 15µH / 44A / 3.0mΩ | 15µH / 30A / 2.2mΩ | 22µH / 90A / 0.9mΩ
Package THT 28x23mm | THT 33.5x28mm | THT 33.5x28mm | THT 33x31.5mm
200kHz 78mV / 31% ripple / Isat margin | 78mV / 89% | 78mV / 29% | 53.4mV / 304%
200kHz 1.40W conduction loss | 1.20W | 0.88W | 0.36W

C54830921 is the best pure value play (+$0.57 for 89% Isat margin, same ripple). HCZH-3218-150-M was chosen instead for its lower DCR (0.88W conduction loss, a real efficiency win) at a still-modest $1.56 premium over the original part — a deliberate prototype-stage trade-off (moderate cost increase for a meaningful efficiency gain, not chasing the maximum-margin C37634008 pick, which cost 2.7x more for headroom this design doesn’t need).

Chosen: HCZH-3218-150-M (YOUCHI, C53699952). Applied to buck_boost.kicad_sch; PCB footprint not yet updated — see STANDARDS.md’s L4 note for status.

### 10.4. Summary

ItemVerdict at 200kHz
MOSFETs (BSC030N08NS5) | Electrically fine (Vds/Rds(on)/Qg headroom unchanged), but switching loss ≈doubles — thermal design (ROADMAP Phase 3) must land first
Gate driver (IRS21867STRPBF) | No concern — propagation delay and drive current have ample margin
Main inductor (L4) | Replacement chosen: HCZH-3218-150-M (C53699952) — clears ripple target at 200kHz, DCR cut from 3.5mΩ to 2.2mΩ (0.88W conduction loss), for a modest $1.56 premium over the original part
Bulk caps / | Frequency-independent, no re-check needed

ItemVerdict at 200kHz
TVS / voltage sensing

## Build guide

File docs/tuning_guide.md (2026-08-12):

# MPPT Tuning & Architecture Guide

## Control Architecture: The Unified Min-Selector
The system has moved away from discrete state-based PID loops. It now uses a **Unified Override Control** model:
1.  **Multiple Deltas**: Every control objective (MPPT, Output CV, Output CC, Input UV, etc.) calculates its own desired change ($\Delta$) in duty cycle.
2.  **Min-Selector**: The controller selects the **minimum** $\Delta$ among all active constraints.
    *   Example: If MPPT wants to increase duty (+10) but Output CV needs to decrease it to stay at 14.4V (-5), the controller picks -5.
3.  **Velocity PI**: The selected $\Delta$ is accumulated into a 64-bit high-resolution integrator, which is then applied to the hardware PWM.

## Telemetry States
The `state` string in the telemetry provides granular feedback on which limit is currently "winning" the selector:
- `MPPT`: No limits hit, MPPT (or the fixed setpoint in CV/CC/PSU modes) is in control.
- `CV`: Output Voltage limit is active (Battery Full).
- `CC`: Output Current limit is active.
- `BROWNOUT`: Input Voltage is dropping below the soft-floor (`vInMin_mV`).
- `REV_V`: Input Voltage is hitting the upper limit in reverse flow (`vInMax_mV`).
- `REV_I_IN`: Reverse current limit is active on the input-side sensor (`iInMin_mA` - protects the source/battery being backfed).
- `REV_I_OUT`: Reverse current limit is active on the output-side sensor (`iOutMin_mA`).

## Control Gains
- `GAIN_KP`: Proportional gain. Currently tuned to **5** for stable transitions on openMPPT v1.1 hardware.
- `GAIN_KI`: Integral gain. Currently **2**.
- `SOFT_LIMIT_HOLD_TIME_MS`: Set to **100ms** to prevent dashboard flickering when bouncing on a limit.

## Lab Setup (Simulated Solar Panel)
To simulate a solar panel curve using a standard 60V/5A Lab PSU:
1.  **Source Side**: Connect the PSU in series with a **4.7 Ω (100W+)** resistor.
2.  **Load Side**: Connect the MPPT output to a **2.2 Ω (200W+)** resistor or a 12V battery.
3.  **Cooling**: Ensure resistors have active cooling.

## Running the Tuning Session
1.  **Environment**: Ensure `pyserial` is installed (`pip install pyserial`).
2.  **Execution**:
    ```bash
    python scripts/tune_mppt.py --port /dev/ttyACM0 --random-iters 15 --fine-iters 10
    ```
3.  **Algorithm**:
    *   **Phase 1 (Random Search)**: Explores step sizes and EMA filtering.
    *   **Phase 2 (Fine Tuning)**: Optimizes around the best local candidate.

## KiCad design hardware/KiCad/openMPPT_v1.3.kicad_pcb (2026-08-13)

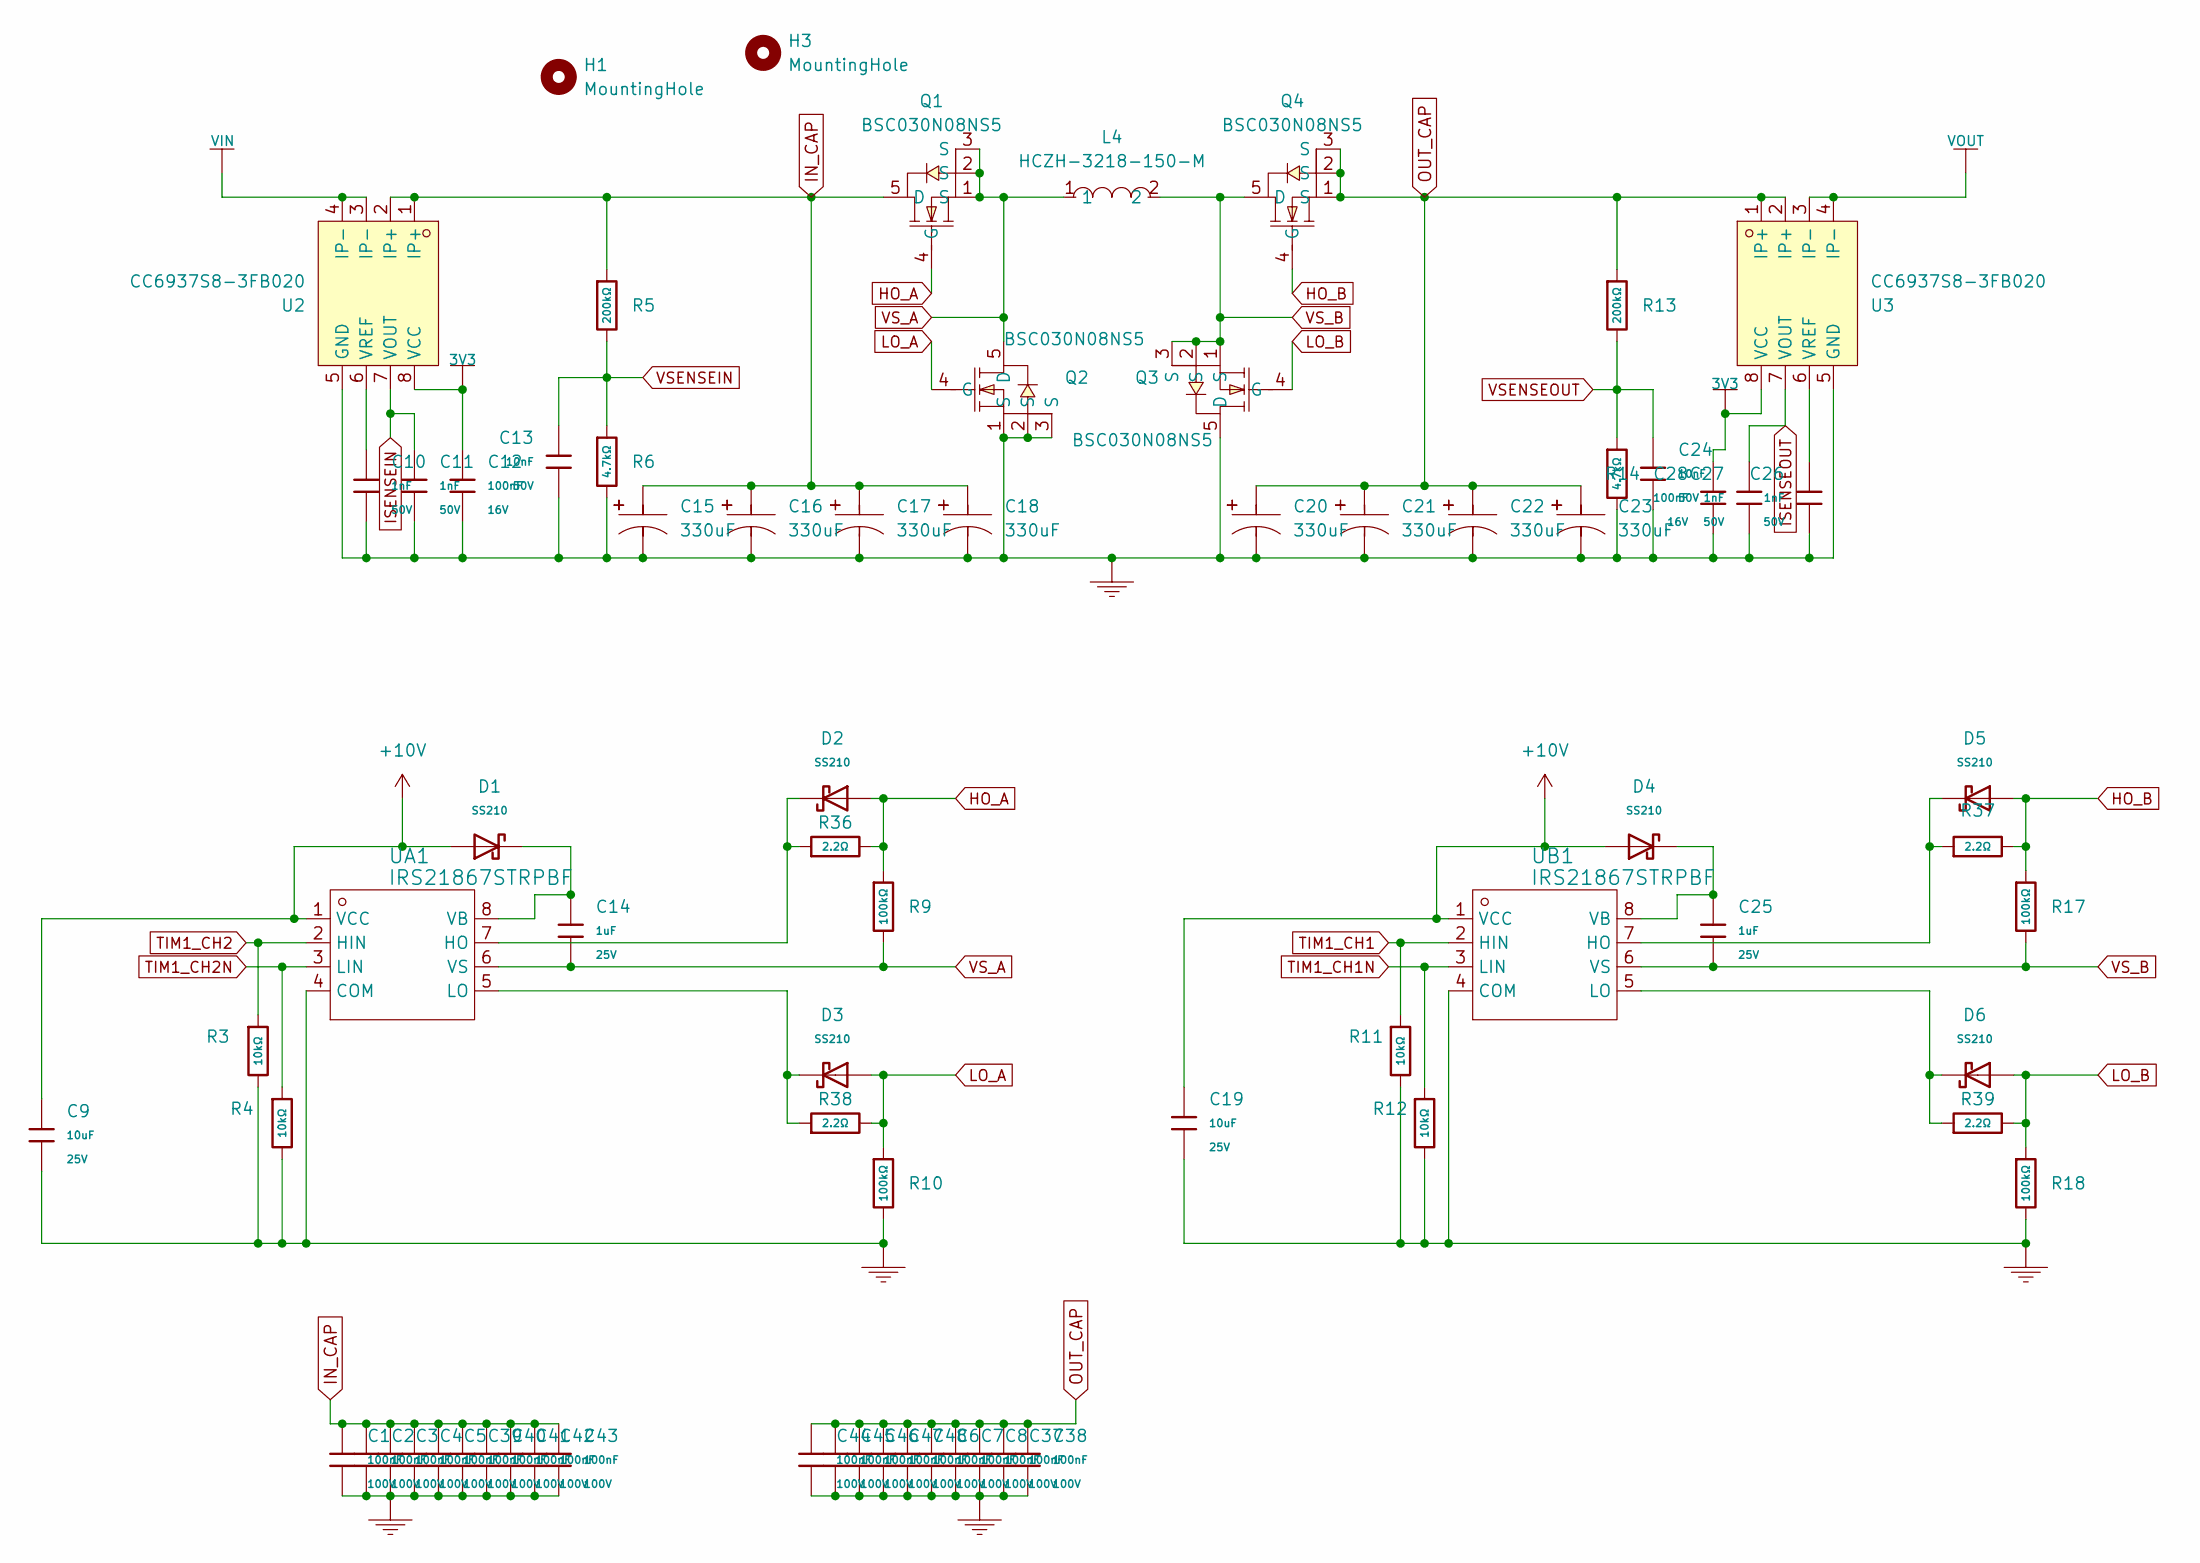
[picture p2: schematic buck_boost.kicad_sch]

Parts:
C1, C2, C3, C4, C5, C6, C7, C8, C37, C38, C39, C40, C41, C42, C43, C44, C45, C46, C47, C48: 100nF; C_0805; Voltage Rated 100V; Tolerance ±10%; Part CL21B104KCFNNNE; LCSC C28233
C9, C19: 10uF; C_0603; Voltage Rated 25V; Tolerance ±20%; Part CL10A106MA8NRNC; LCSC C96446
C10, C11, C26, C27: 1nF; C_0402; Voltage Rated 50V; Tolerance ±10%; Part 0402B102K500NT; LCSC C1523
C12, C28: 100nF; C_0402; Voltage Rated 16V; Tolerance ±10%; Part CL05B104KO5NNNC; LCSC C1525
C13, C24: 10nF; C_0402; Voltage Rated 50V; Tolerance ±10%; Part CL05B103KB5NNNC; LCSC C15195
C14, C25: 1uF; C_0402; Voltage Rated 25V; Tolerance ±10%; Part CL05A105KA5NQNC; LCSC C52923
C15, C16, C17, C18, C20, C21, C22, C23: 330uF; CAP-TH_BD12.5-P5.00-D0.6-FD; MPN LKML2502A331MF; LCSC Part C443153
D1, D2, D3, D4, D5, D6: SS210; D_SMA; Forward Voltage (Vf@If) 850mV@2A; Reverse Voltage (Vr) 100V; Part SS210; LCSC C14996
H1, H3: MountingHole; MountingHole_3.2mm_M3_DIN965
L4: HCZH-3218-150-M; IND-TH_L33.5-W23.0-P12.00_HCZH-3218; MPN HCZH-3218-150-M; LCSC Part C53699952
Q1, Q2, Q3, Q4: BSC030N08NS5; PG-TDSON-8_L5.0-W6.0-P1.27-BL-EP; MPN BSC030N08NS5; LCSC Part C501507
R3, R4, R11, R12: 10kΩ; R_0402; Overload Voltage (Max) 50V; Tolerance ±1%; Part 0402WGF1002TCE; LCSC C25744
R5, R13: 200kΩ; R_0603; Overload Voltage (Max) 75V; Tolerance ±1%; Part 0603WAF2003T5E; LCSC C25811
R6, R14: 4.7kΩ; R_0603; Overload Voltage (Max) 75V; Tolerance ±1%; Part 0603WAF4701T5E; LCSC C23162
R9, R10, R17, R18: 100kΩ; R_0603; Overload Voltage (Max) 75V; Tolerance ±1%; Part 0603WAF1003T5E; LCSC C25803
R36, R37, R38, R39: 2.2Ω; R_0603; Overload Voltage (Max) 75V; Tolerance ±1%; Part 0603WAF220KT5E; LCSC C22939
U2, U3: CC6937S8-3FB020; SOP-8_L4.9-W3.9-P1.27-LS6.0-BL; MPN CC6937S8-3FB020; LCSC Part C41421919
UA1: IRS21867STRPBF; SOIC-8_L5.0-W4.0-P1.27-LS6.0-BL; Manufacturer Part IRS21867STRPBF
UB1: IRS21867STRPBF; SOIC-8_L5.0-W4.0-P1.27-LS6.0-BL; Manufacturer Part IRS21867STRPBF

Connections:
3V3: C12.1, C28.1, U2.8 (VCC), U3.8 (VCC); also elsewhere on the board
+10V: C9.1, C19.1, D1.2, D4.2, UA1.1 (VCC), UB1.1 (VCC); also elsewhere on the board
GND: C1.2, C2.2, C3.2, C4.2, C5.2, C6.2, C7.2, C8.2, C9.2, C10.2, C11.2, C12.2, C13.2, C15.2 (-), C16.2 (-), C17.2 (-), C18.2 (-), C19.2, C20.2 (-), C21.2 (-), C22.2 (-), C23.2 (-), C24.2, C26.2, C27.2, C28.2, C37.2, C38.2, C39.2, C40.2, C41.2, C42.2, C43.2, C44.2, C45.2, C46.2, C47.2, C48.2, Q2.1 (S), Q2.2 (S), Q2.3 (S), Q3.5 (D), R3.2, R4.2, R6.2, R10.2, R11.2, R12.2, R14.2, R18.2, U2.5 (GND), U3.5 (GND), UA1.4 (COM), UB1.4 (COM); also elsewhere on the board
HO_A: D2.2, Q1.4 (G), R9.1, R36.2
HO_B: D5.2, Q4.4 (G), R17.1, R37.2
IN_CAP: C1.1, C2.1, C3.1, C4.1, C5.1, C15.1 (+), C16.1 (+), C17.1 (+), C18.1 (+), C39.1, C40.1, C41.1, C42.1, C43.1, Q1.5 (D), R5.1, U2.1 (IP+), U2.2 (IP+)
ISENSEIN: C11.1, U2.7 (VOUT); also elsewhere on the board
ISENSEOUT: C27.1, U3.7 (VOUT); also elsewhere on the board
LO_A: D3.2, Q2.4 (G), R10.1, R38.2
LO_B: D6.2, Q3.4 (G), R18.1, R39.2
unnamed: C10.1, U2.6 (VREF)
unnamed: C26.1, U3.6 (VREF)
unnamed: D2.1, R36.1, UA1.7 (HO)
unnamed: D3.1, R38.1, UA1.5 (LO)
unnamed: C14.1, D1.1, UA1.8 (VB)
unnamed: D5.1, R37.1, UB1.7 (HO)
unnamed: D6.1, R39.1, UB1.5 (LO)
unnamed: C25.1, D4.1, UB1.8 (VB)
OUT_CAP: C6.1, C7.1, C8.1, C20.1 (+), C21.1 (+), C22.1 (+), C23.1 (+), C37.1, C38.1, C44.1, C45.1, C46.1, C47.1, C48.1, Q4.1 (S), Q4.2 (S), Q4.3 (S), R13.1, U3.1 (IP+), U3.2 (IP+)
TIM1_CH1: R11.1, UB1.2 (HIN); also elsewhere on the board
TIM1_CH1N: R12.1, UB1.3 (LIN); also elsewhere on the board
TIM1_CH2: R3.1, UA1.2 (HIN); also elsewhere on the board
TIM1_CH2N: R4.1, UA1.3 (LIN); also elsewhere on the board
VIN: U2.3 (IP-), U2.4 (IP-); also elsewhere on the board
VOUT: U3.3 (IP-), U3.4 (IP-); also elsewhere on the board
VSENSEIN: C13.1, R5.2, R6.1; also elsewhere on the board
VSENSEOUT: C24.1, R13.2, R14.1; also elsewhere on the board
VS_A: C14.2, L4.1, Q1.1 (S), Q1.2 (S), Q1.3 (S), Q2.5 (D), R9.2, UA1.6 (VS)
VS_B: C25.2, L4.2, Q3.1 (S), Q3.2 (S), Q3.3 (S), Q4.5 (D), R17.2, UB1.6 (VS)

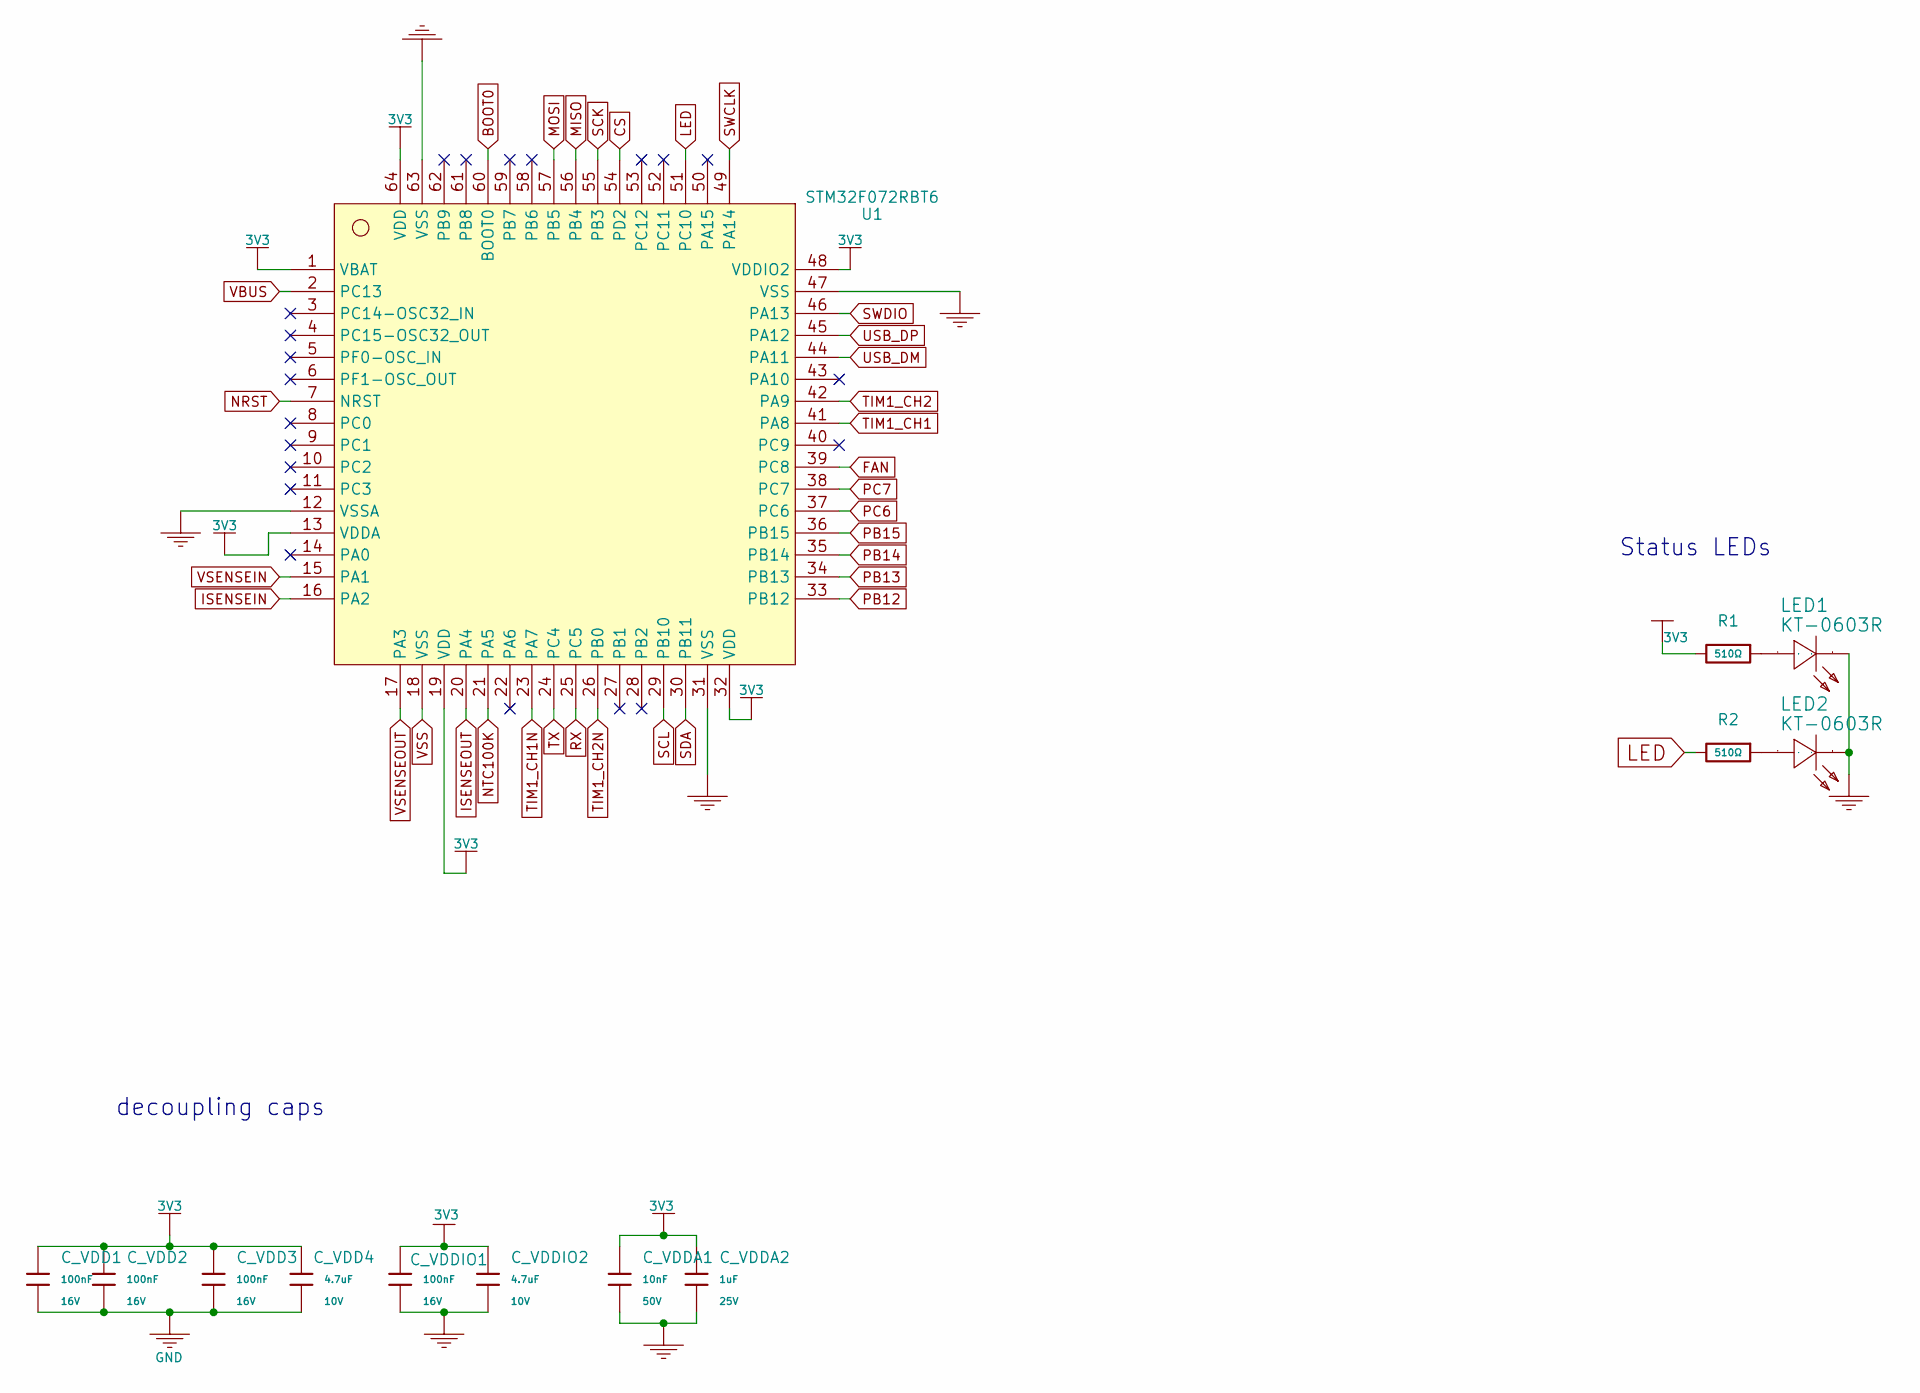
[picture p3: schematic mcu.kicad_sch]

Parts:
C_VDD1, C_VDD2, C_VDD3: 100nF; C_0402; Voltage Rated 16V; Tolerance ±10%; Part CL05B104KO5NNNC; LCSC C1525
C_VDD4: 4.7uF; C_0402; Voltage Rated 10V; Tolerance ±20%; Part CL05A475MP5NRNC; LCSC C23733
C_VDDA1: 10nF; C_0402; Voltage Rated 50V; Tolerance ±10%; Part CL05B103KB5NNNC; LCSC C15195
C_VDDA2: 1uF; C_0402; Voltage Rated 25V; Tolerance ±10%; Part CL05A105KA5NQNC; LCSC C52923
C_VDDIO1: 100nF; C_0402; Voltage Rated 16V; Tolerance ±10%; Part CL05B104KO5NNNC; LCSC C1525
C_VDDIO2: 4.7uF; C_0402; Voltage Rated 10V; Tolerance ±20%; Part CL05A475MP5NRNC; LCSC C23733
LED1, LED2: KT-0603R; LED_0603_1608Metric; Manufacturer Part KT-0603R
R1, R2: 510Ω; R_0402; Overload Voltage (Max) 50V; Tolerance ±1%; Part 0402WGF5100TCE; LCSC C25123
U1: STM32F072RBT6; LQFP-64_L10.0-W10.0-P0.50-LS12.0-BL; MPN STM32F072RBT6; LCSC Part C46046

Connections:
3V3: C_VDD1.1, C_VDD2.1, C_VDD3.1, C_VDD4.1, C_VDDA1.1, C_VDDA2.1, C_VDDIO1.1, C_VDDIO2.1, R1.2, U1.1 (VBAT), U1.13 (VDDA), U1.19 (VDD), U1.32 (VDD), U1.48 (VDDIO2), U1.64 (VDD); also elsewhere on the board
BOOT0: U1.60 (BOOT0); also elsewhere on the board
CS: U1.54 (PD2); also elsewhere on the board
FAN: U1.39 (PC8); also elsewhere on the board
GND: C_VDD1.2, C_VDD2.2, C_VDD3.2, C_VDD4.2, C_VDDA1.2, C_VDDA2.2, C_VDDIO1.2, C_VDDIO2.2, LED1.1 (K), LED2.1 (K), U1.12 (VSSA), U1.31 (VSS), U1.47 (VSS), U1.63 (VSS); also elsewhere on the board
ISENSEIN: U1.16 (PA2); also elsewhere on the board
ISENSEOUT: U1.20 (PA4); also elsewhere on the board
LED: R2.2, U1.51 (PC10)
MISO: U1.56 (PB4); also elsewhere on the board
MOSI: U1.57 (PB5); also elsewhere on the board
NRST: U1.7 (NRST); also elsewhere on the board
NTC100K: U1.21 (PA5); also elsewhere on the board
unnamed: LED1.2 (A), R1.1
unnamed: LED2.2 (A), R2.1
PB12: U1.33 (PB12); also elsewhere on the board
PB13: U1.34 (PB13); also elsewhere on the board
PB14: U1.35 (PB14); also elsewhere on the board
PB15: U1.36 (PB15); also elsewhere on the board
PC6: U1.37 (PC6); also elsewhere on the board
PC7: U1.38 (PC7); also elsewhere on the board
RX: U1.25 (PC5); also elsewhere on the board
SCK: U1.55 (PB3); also elsewhere on the board
SCL: U1.29 (PB10); also elsewhere on the board
SDA: U1.30 (PB11); also elsewhere on the board
SWCLK: U1.49 (PA14); also elsewhere on the board
SWDIO: U1.46 (PA13); also elsewhere on the board
TIM1_CH1: U1.41 (PA8); also elsewhere on the board
TIM1_CH1N: U1.23 (PA7); also elsewhere on the board
TIM1_CH2: U1.42 (PA9); also elsewhere on the board
TIM1_CH2N: U1.26 (PB0); also elsewhere on the board
TX: U1.24 (PC4); also elsewhere on the board
USB_DM: U1.44 (PA11); also elsewhere on the board
USB_DP: U1.45 (PA12); also elsewhere on the board
VBUS: U1.2 (PC13); also elsewhere on the board
VSENSEIN: U1.15 (PA1); also elsewhere on the board
VSENSEOUT: U1.17 (PA3); also elsewhere on the board
VSS: U1.18 (VSS)

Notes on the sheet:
Status LEDs
decoupling caps

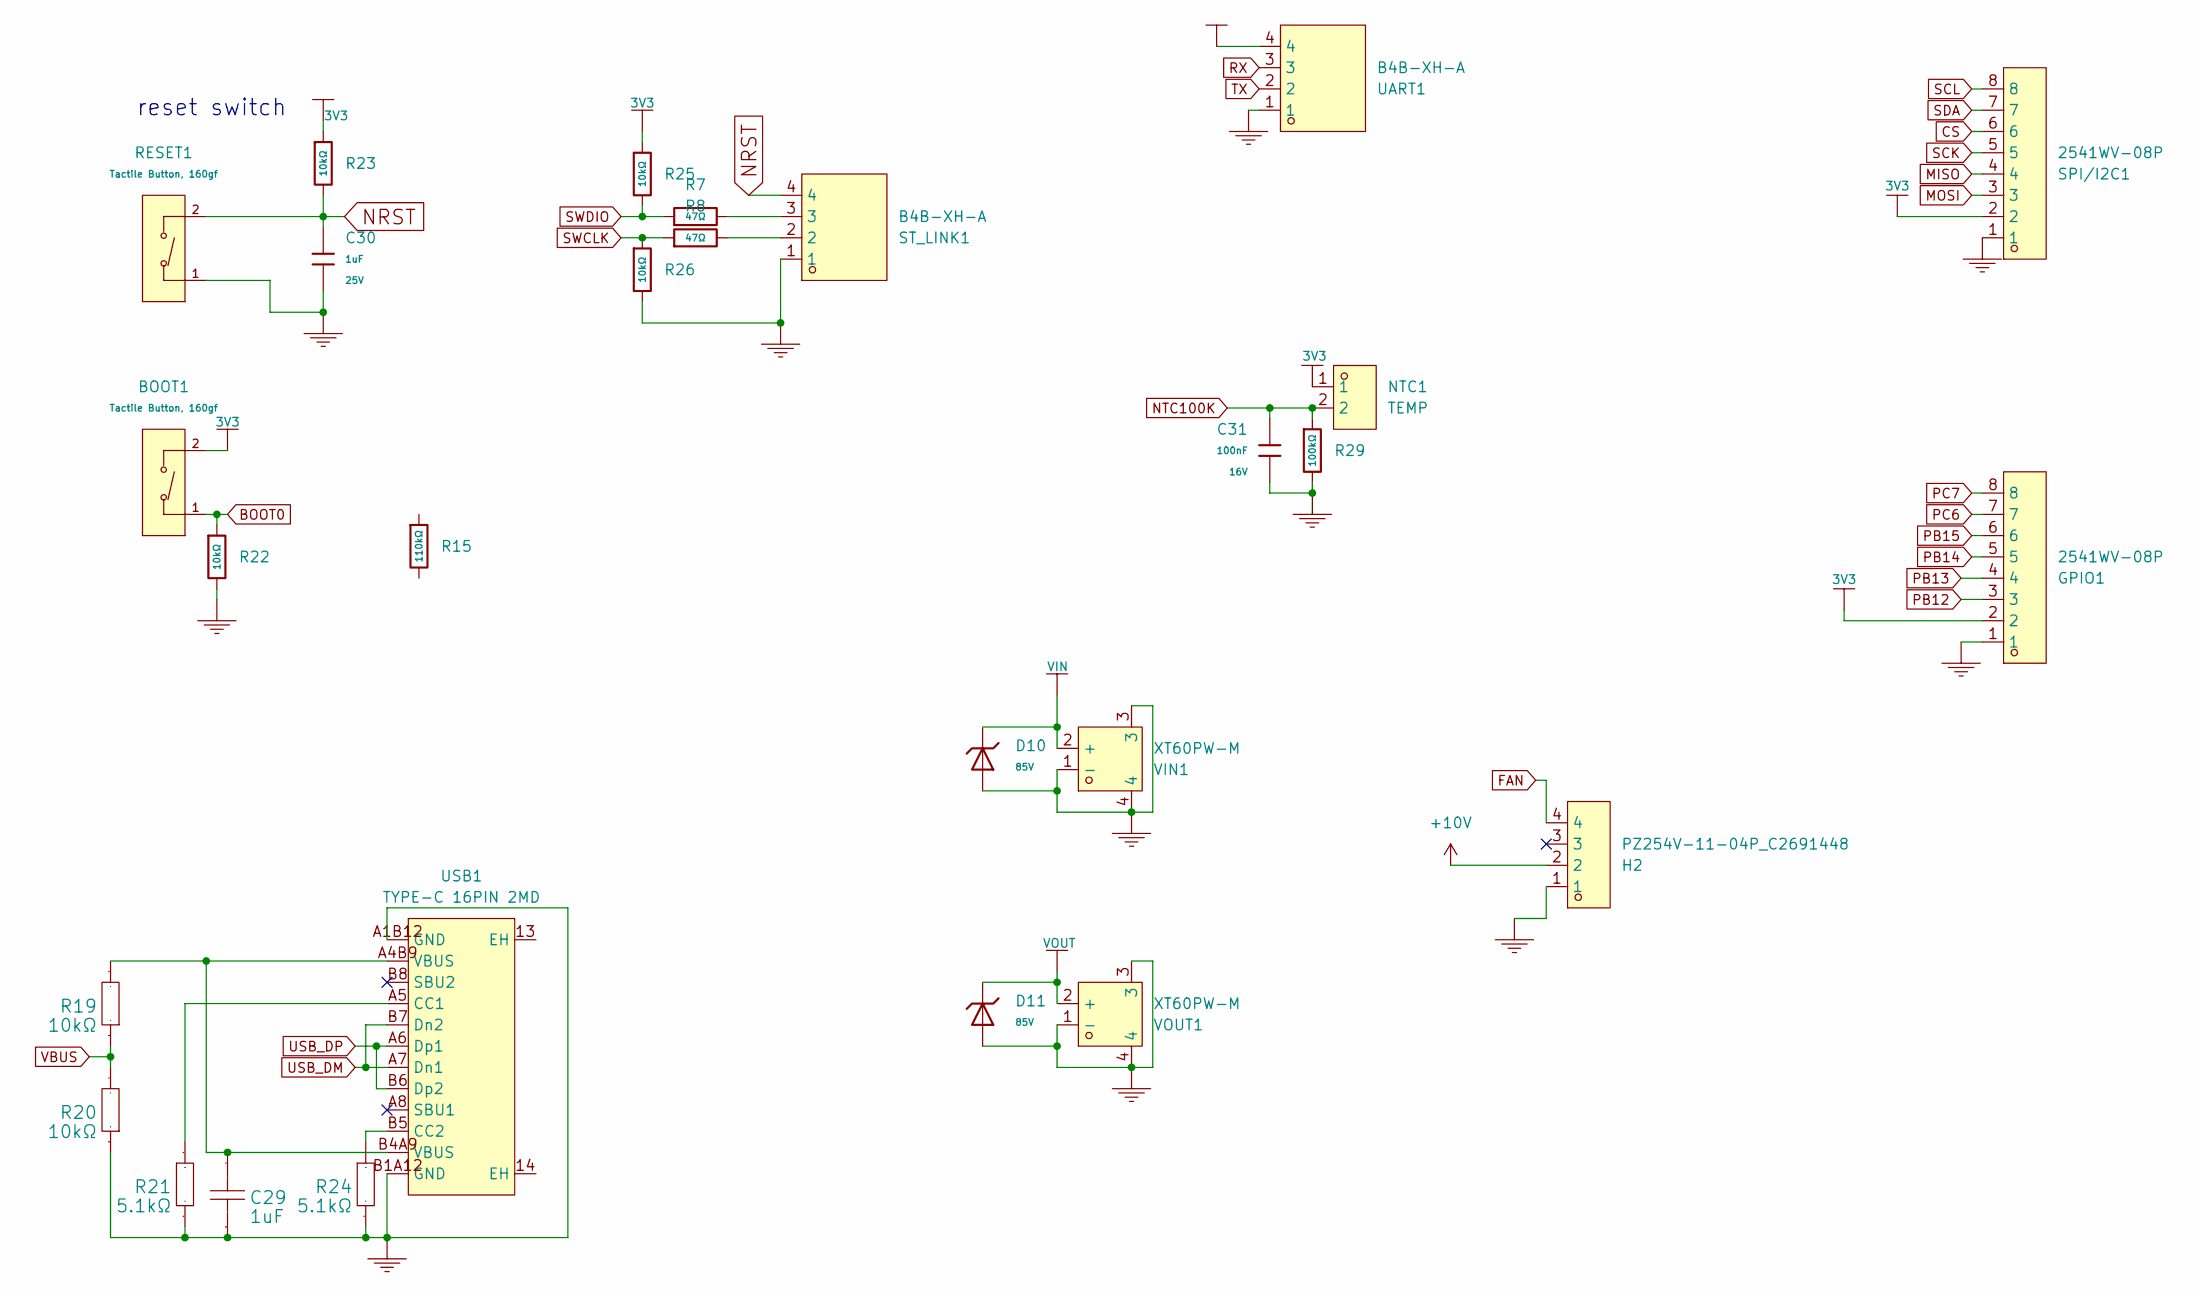
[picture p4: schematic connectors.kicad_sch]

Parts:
BOOT1: Tactile Button, 160gf; SW_TS-1088-AR02016; Voltage Rating (Dc) 12V; Part TS-1088-AR02016; LCSC C720477
C29: 1uF; C_0402_1005Metric; Manufacturer Part CL05A105KA5NQNC
C30: 1uF; C_0402; Voltage Rated 25V; Tolerance ±10%; Part CL05A105KA5NQNC; LCSC C52923
C31: 100nF; C_0402; Voltage Rated 16V; Tolerance ±10%; Part CL05B104KO5NNNC; LCSC C1525
D10, D11: 85V; D_SMC; Clamping Voltage 137V; Voltage - Breakdown 104V; Part 5.0SMDJ85CA; LCSC C42394457
GPIO1: 2541WV-08P; HDR-TH_8P-P2.54-V-M-4; MPN 2541WV-08P; LCSC Part C5383116
H2: PZ254V-11-04P_C2691448; HDR-TH_4P-P2.54-V-M; MPN PZ254V-11-04P; LCSC Part C2691448
NTC1: TEMP; HDR-TH_2P-P2.54-V-M; MPN PZ254V-11-02P; LCSC Part C492401
R7, R8: 47Ω; R_0603; Overload Voltage (Max) 75V; Tolerance ±1%; Part 0603WAF470JT5E; LCSC C23182
R15: 110kΩ; R_0603; Overload Voltage (Max) 75V; Tolerance ±1%; Part 0603WAF1103T5E; LCSC C25805
R19, R20: 10kΩ; R_0402_1005Metric; Manufacturer Part 0402WGF1002TCE
R21, R24: 5.1kΩ; R_0402_1005Metric; Manufacturer Part 0402WGF5101TCE
R22, R23, R25, R26: 10kΩ; R_0402; Overload Voltage (Max) 50V; Tolerance ±1%; Part 0402WGF1002TCE; LCSC C25744
R29: 100kΩ; R_0402; Overload Voltage (Max) 50V; Tolerance ±1%; Part 0402WGF1003TCE; LCSC C25741
RESET1: Tactile Button, 160gf; SW_TS-1088-AR02016; Voltage Rating (Dc) 12V; Part TS-1088-AR02016; LCSC C720477
SPI/I2C1: 2541WV-08P; HDR-TH_8P-P2.54-V-M-4; MPN 2541WV-08P; LCSC Part C5383116
ST_LINK1: B4B-XH-A; CONN-TH_B4B-XH-A-LF-SN; MPN B4B-XH-A(LF)(SN); LCSC Part C144395
UART1: B4B-XH-A; CONN-TH_B4B-XH-A-LF-SN; MPN B4B-XH-A(LF)(SN); LCSC Part C144395
USB1: TYPE-C 16PIN 2MD; USB-C-SMD_TYPE-C-16PIN-2MD-073; MPN TYPE-C 16PIN 2MD(073); LCSC Part C2765186
VIN1: XT60PW-M; CONN-TH_XT60PW-M; MPN XT60PW-M; LCSC Part C98732
VOUT1: XT60PW-M; CONN-TH_XT60PW-M; MPN XT60PW-M; LCSC Part C98732

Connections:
3V3: BOOT1.2 (B), GPIO1.2, NTC1.1, R23.1, R25.1, SPI/I2C1.2, UART1.4; also elsewhere on the board
+10V: H2.2; also elsewhere on the board
BOOT0: BOOT1.1 (A), R22.1; also elsewhere on the board
CS: SPI/I2C1.6; also elsewhere on the board
FAN: H2.4; also elsewhere on the board
GND: C29.1, C30.2, C31.2, D10.2, D11.2, GPIO1.1, H2.1, R20.1, R21.2, R22.2, R24.2, R26.2, R29.2, RESET1.1 (A), SPI/I2C1.1, ST_LINK1.1, UART1.1, USB1.A1B12 (GND), USB1.B1A12 (GND), VIN1.1 (-), VIN1.3, VIN1.4, VOUT1.1 (-), VOUT1.3, VOUT1.4; also elsewhere on the board
MISO: SPI/I2C1.4; also elsewhere on the board
MOSI: SPI/I2C1.3; also elsewhere on the board
NRST: C30.1, R23.2, RESET1.2 (B), ST_LINK1.4; also elsewhere on the board
NTC100K: C31.1, NTC1.2, R29.1; also elsewhere on the board
unnamed: C29.2, R19.2, USB1.A4B9 (VBUS), USB1.B4A9 (VBUS)
unnamed: R7.2, ST_LINK1.3
unnamed: R8.2, ST_LINK1.2
unnamed: R21.1, USB1.A5 (CC1)
unnamed: R24.1, USB1.B5 (CC2)
PB12: GPIO1.3; also elsewhere on the board
PB13: GPIO1.4; also elsewhere on the board
PB14: GPIO1.5; also elsewhere on the board
PB15: GPIO1.6; also elsewhere on the board
PC6: GPIO1.7; also elsewhere on the board
PC7: GPIO1.8; also elsewhere on the board
RX: UART1.3; also elsewhere on the board
SCK: SPI/I2C1.5; also elsewhere on the board
SCL: SPI/I2C1.8; also elsewhere on the board
SDA: SPI/I2C1.7; also elsewhere on the board
SWCLK: R8.1, R26.1; also elsewhere on the board
SWDIO: R7.1, R25.2; also elsewhere on the board
TX: UART1.2; also elsewhere on the board
USB_DM: USB1.A7 (Dn1), USB1.B7 (Dn2); also elsewhere on the board
USB_DP: USB1.A6 (Dp1), USB1.B6 (Dp2); also elsewhere on the board
VBUS: R19.1, R20.2; also elsewhere on the board
VIN: D10.1, VIN1.2 (+); also elsewhere on the board
VOUT: D11.1, VOUT1.2 (+); also elsewhere on the board

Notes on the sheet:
reset switch

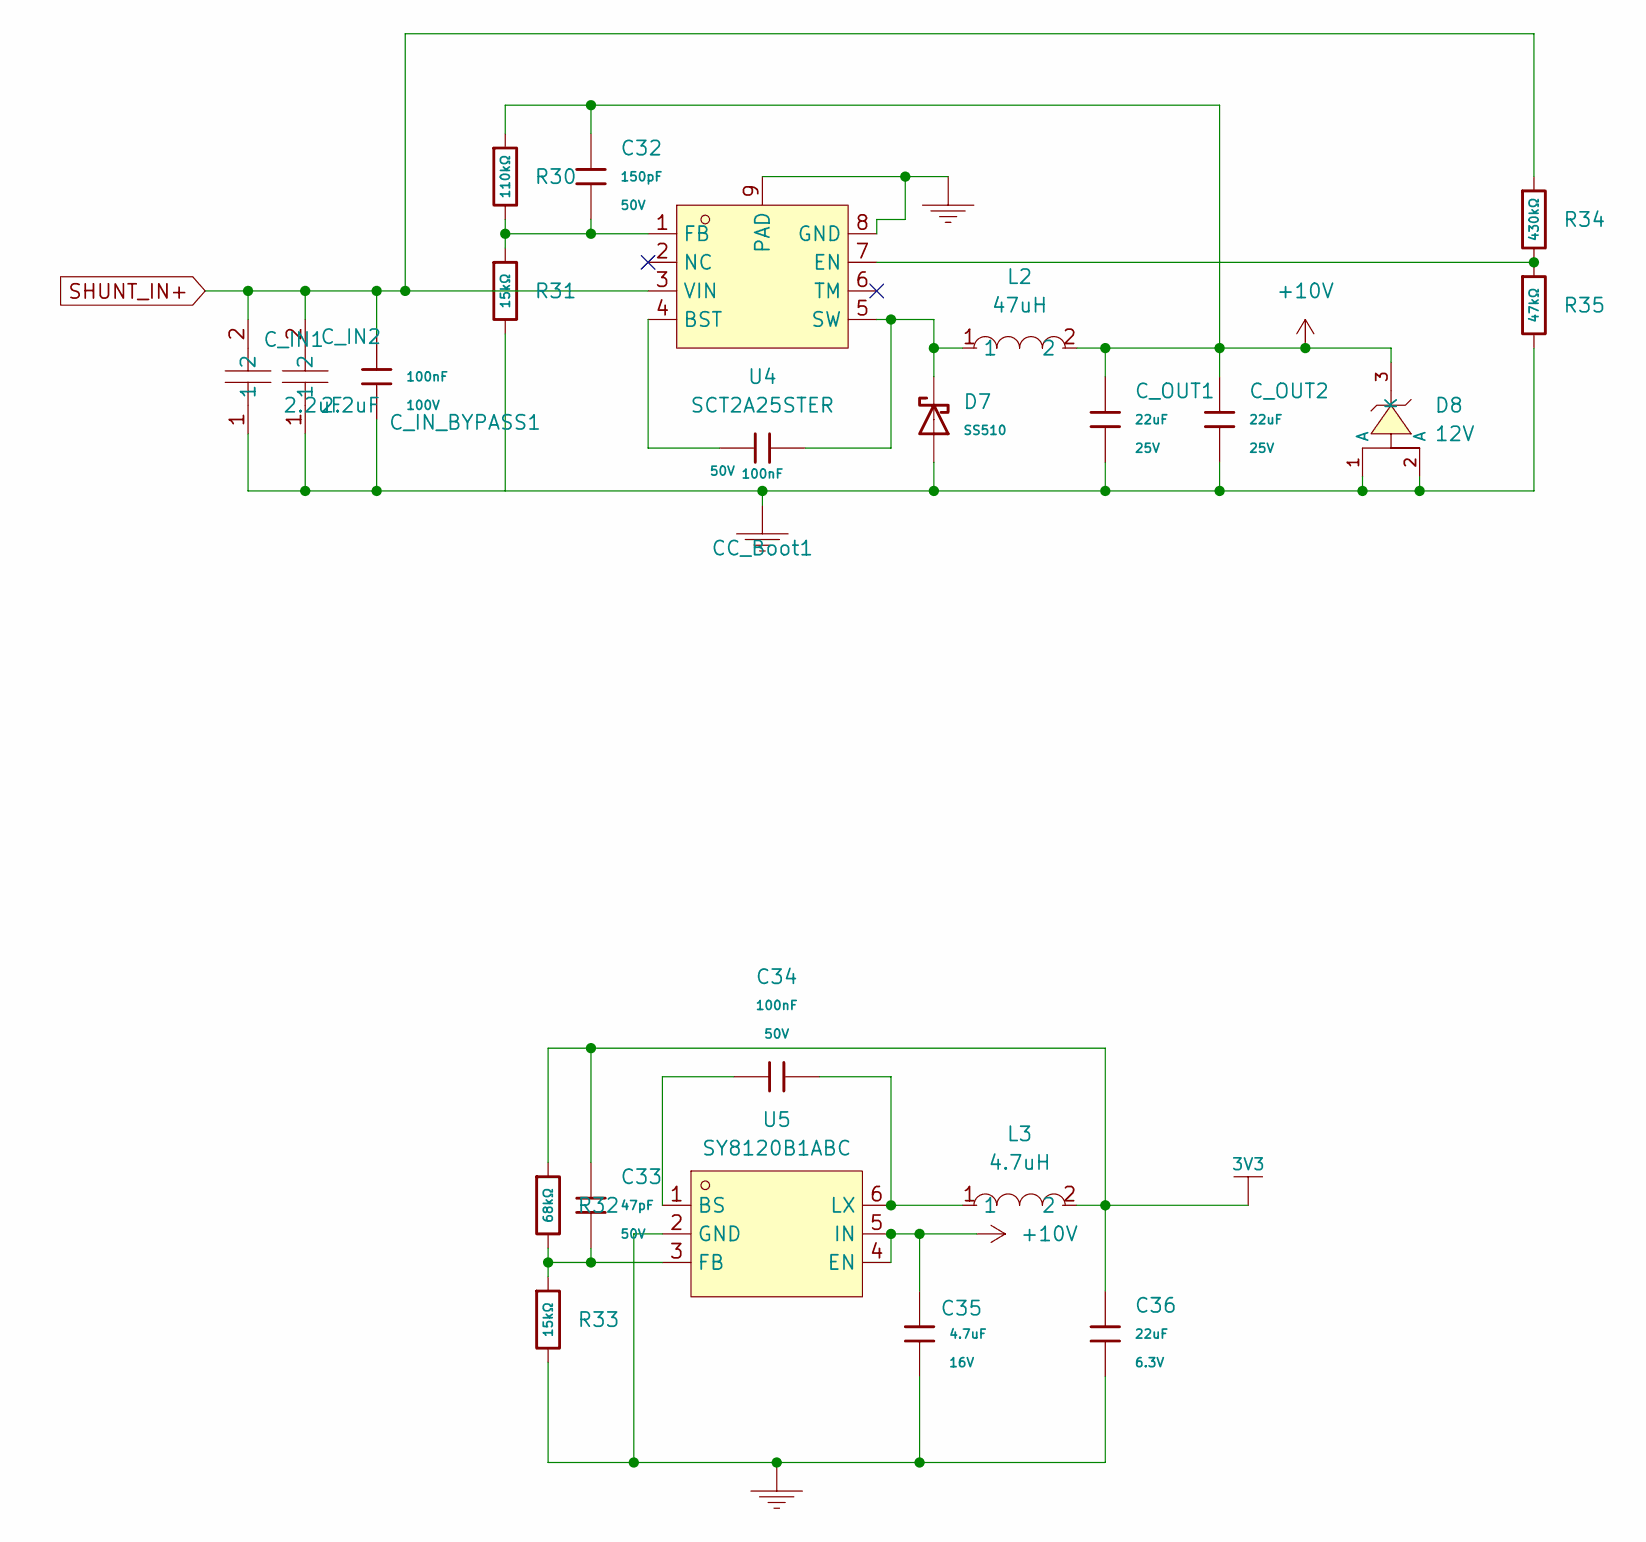
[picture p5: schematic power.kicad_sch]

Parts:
C32: 150pF; C_0603; Voltage Rated 50V; Tolerance ±10%; Part 0603B151K500NT; LCSC C1594
C33: 47pF; C_0603; Voltage Rated 50V; Tolerance ±5%; Part CL10C470JB8NNNC; LCSC C1671
C34: 100nF; C_0603; Voltage Rated 50V; Tolerance ±10%; Part CC0603KRX7R9BB104; LCSC C14663
C35: 4.7uF; C_0603; Voltage Rated 16V; Tolerance ±10%; Part CL10A475KO8NNNC; LCSC C19666
C36: 22uF; C_0603; Voltage Rated 6.3V; Tolerance ±20%; Part CL10A226MQ8NRNC; LCSC C59461
CC_Boot1: 100nF; C_0603; Voltage Rated 50V; Tolerance ±10%; Part CC0603KRX7R9BB104; LCSC C14663
C_IN1, C_IN2: 2.2uF; C1210; MPN TCC1210X7R225K101MT; LCSC Part C5449052
C_IN_BYPASS1: 100nF; C_0805; Voltage Rated 100V; Tolerance ±10%; Part CL21B104KCFNNNE; LCSC C28233
C_OUT1, C_OUT2: 22uF; C_0805; Voltage Rated 25V; Tolerance ±20%; Part CL21A226MAQNNNE; LCSC C45783
D7: SS510; D_SMA; Forward Voltage (Vf@If) 850mV@5A; Reverse Voltage (Vr) 100V; Part SS510; LCSC C7420368
D8: 12V; DFN2020-3_L2.0-W2.0-P0.65-BR-1; Part H12VH22U; LCSC C20615799
L2: 47uH; IND-SMD_L12.5-W12.5-1; MPN GXDR1207-470MT; LCSC Part C52196367
L3: 4.7uH; IND-SMD_L2.0-W1.6-B; MPN FTC201610S4R7MBCA; LCSC Part C5832346
R30: 110kΩ; R_0603; Overload Voltage (Max) 75V; Tolerance ±1%; Part 0603WAF1103T5E; LCSC C25805
R31, R33: 15kΩ; R_0603; Overload Voltage (Max) 75V; Tolerance ±1%; Part 0603WAF1502T5E; LCSC C22809
R32: 68kΩ; R_0603; Overload Voltage (Max) 75V; Tolerance ±1%; Part 0603WAF6802T5E; LCSC C23231
R34: 430kΩ; R_0603; Overload Voltage (Max) 75V; Tolerance ±1%; Part 0603WAF4303T5E; LCSC C25969
R35: 47kΩ; R_0603; Overload Voltage (Max) 75V; Tolerance ±1%; Part 0603WAF4702T5E; LCSC C25819
U4: SCT2A25STER; ESOP-8_L4.9-W3.9-P1.27-LS6.0-BL-EP; MPN SCT2A25STER; LCSC Part C5124114
U5: SY8120B1ABC; SOT-23-6_L2.9-W1.6-P0.95-LS2.8-BL; MPN SY8120B1ABC; LCSC Part C88474

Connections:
3V3: C33.1, C36.1, L3.2, R32.1; also elsewhere on the board
+10V: C32.1, C35.1, C_OUT1.1, C_OUT2.1, D8.3 (K), L2.2, R30.1, U5.4 (EN), U5.5 (IN); also elsewhere on the board
GND: C35.2, C36.2, C_IN1.1, C_IN2.1, C_IN_BYPASS1.2, C_OUT1.2, C_OUT2.2, D7.2, D8.1 (A), D8.2 (A), R33.2, R35.2, U4.8 (GND), U4.9 (PAD), U5.2 (GND); also elsewhere on the board
unnamed: CC_Boot1.1, U4.4 (BST)
unnamed: R34.2, R35.1, U4.7 (EN)
unnamed: C32.2, R30.2, R31.1, U4.1 (FB)
unnamed: CC_Boot1.2, D7.1, L2.1, U4.5 (SW)
unnamed: C34.1, U5.1 (BS)
unnamed: C33.2, R32.2, R33.1, U5.3 (FB)
unnamed: C34.2, L3.1, U5.6 (LX)
SHUNT_IN+: C_IN1.2, C_IN2.2, C_IN_BYPASS1.1, R34.1, U4.3 (VIN)

Board: 2 copper layers, 137 parts (0 on the bottom side), 68 nets, no tracks yet.

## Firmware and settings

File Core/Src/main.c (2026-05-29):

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
/* Includes ------------------------------------------------------------------*/
#include "main.h"
#include "adc.h"
#include "dma.h"
#include "i2c.h"
#include "spi.h"
#include "tim.h"
#include "usart.h"
#include "usb_device.h"
#include "gpio.h"

/* USER CODE BEGIN Includes */
#include "sensors.h"
#include "power.h"
#include "controller.h"
#include "comms.h"
#include "settings.h"
#include "system_config.h"
#include "usbd_cdc_if.h"
#include "lcd_pcd8544.h"
/* USER CODE END Includes */

IWDG_HandleTypeDef hiwdg;

/* USER CODE BEGIN PV */
LCD_Handle_t hlcd;
static uint32_t lastLCDTick = 0;
/* USER CODE END PV */

void SystemClock_Config(void);
static void MX_IWDG_Init(void);
/**
 * @brief  The application entry point.
 * @retval int
 */
int main(void)
{
  /* MCU Configuration--------------------------------------------------------*/

  /* Reset of all peripherals, Initializes the Flash interface and the Systick. */
  HAL_Init();

  /* Configure the system clock */
  SystemClock_Config();

  /* Initialize all configured peripherals */
  MX_GPIO_Init();
  MX_DMA_Init();
  MX_I2C2_Init();
  MX_TIM1_Init();
  MX_USART3_UART_Init();
  MX_USB_DEVICE_Init();
  MX_SPI1_Init();
  MX_TIM2_Init();
  MX_ADC_Init();
  MX_TIM3_Init();
  MX_TIM6_Init();
  MX_IWDG_Init();

  /* USER CODE BEGIN 2 */
  SETTINGS_Init();
  SENSORS_Init();
  POWER_Init();
  CONTROLLER_Init();
  COMMS_Init();

  /* LCD Initialization */
  hlcd.hspi = &hspi1;
  hlcd.port_ce = LCD_CE_GPIO_Port;
  hlcd.pin_ce = LCD_CE_Pin;
  hlcd.port_dc = LCD_DC_GPIO_Port;
  hlcd.pin_dc = LCD_DC_Pin;
  hlcd.port_rst = LCD_RST_GPIO_Port;
  hlcd.pin_rst = LCD_RST_Pin;
  LCD_Init(&hlcd);
  LCD_DrawString(&hlcd, 0, 0, "openMPPT v1.2");
  LCD_Update(&hlcd);
  /* USER CODE END 2 */

  /* Infinite loop */
  /* USER CODE BEGIN WHILE */
  while (1)
  {
    HAL_IWDG_Refresh(&hiwdg);
    COMMS_HandleCommands();

    uint8_t readyStatus = SENSORS_IsBufferReady();
    if (readyStatus) 
    {
      uint16_t offset = (readyStatus == 2) ? (ADC_BUF_LEN / 2) : 0;
      SENSORS_ClearBufferReady();

      SENSORS_Process(offset);
      CONTROLLER_UpdateHighRate();
    }

    CONTROLLER_Task();

    /* UI Refresh Task (10Hz) */
    uint32_t currentTick = HAL_GetTick();
    if (currentTick - lastLCDTick >= 100) {
      lastLCDTick = currentTick;
      const Measurements_t *m = SENSORS_GetMeasurements();
      char line[20];

      LCD_Clear(&hlcd);
      
      sprintf(line, "Vin:  %3ld.%01ldV", m->voltageIn_mV / 1000, (uint32_t)abs(m->voltageIn_mV % 1000) / 100);
      LCD_DrawString(&hlcd, 0, 0, line);
      
      sprintf(line, "Vout: %3ld.%01ldV", m->voltageOut_mV / 1000, (uint32_t)abs(m->voltageOut_mV % 1000) / 100);
      LCD_DrawString(&hlcd, 0, 8, line);
      
      sprintf(line, "Pout: %3ld.%01ldW", m->powerOut_mW / 1000, (uint32_t)abs(m->powerOut_mW % 1000) / 100);
      LCD_DrawString(&hlcd, 0, 16, line);
      
      sprintf(line, "Mode: %s     ", CONTROLLER_GetStateString()); // Added spaces to clear previous text
      LCD_DrawString(&hlcd, 0, 32, line);
      
      LCD_Update(&hlcd);
    }
    /* USER CODE END WHILE */

    /* USER CODE BEGIN 3 */
  }
  /* USER CODE END 3 */
}

/**
  * @brief IWDG Initialization Function
  * @param None
  * @retval None
  */
static void MX_IWDG_Init(void)
{
  /* IWDG clock is LSI (approx 40kHz) */
  /* Timeout = (Prescaler * Reload) / LSI */
  /* Timeout = (64 * 625) / 40000 = 1.0 seconds */
  hiwdg.Instance = IWDG;
  hiwdg.Init.Prescaler = IWDG_PRESCALER_64;
  hiwdg.Init.Window = IWDG_WINDOW_DISABLE;
  hiwdg.Init.Reload = 625;
  if (HAL_IWDG_Init(&hiwdg) != HAL_OK)
  {
    Error_Handler();
  }
}

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
/* USER CODE BEGIN 4 */
// needed for printf
int _write(int file, char *ptr, int len)
{
  static uint8_t rc = USBD_OK;
  uint32_t timeout = 0;

  do
  {
    rc = CDC_Transmit_FS((uint8_t *)ptr, len);
    if (++timeout > 10000) break; // Timeout to prevent blocking without host
  } while (USBD_BUSY == rc);

  if (USBD_FAIL == rc)
  {
    return 0;
  }
  return len;
}
/* USER CODE END 4 */
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


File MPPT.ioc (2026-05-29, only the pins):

Mcu.UserName=STM32F072RBTx
PA1.GPIO_Label=VsenseIn
PA1.Signal=ADC_IN1
PA11.Signal=USB_DM
PA12.Signal=USB_DP
PA13.Signal=SYS_SWDIO
PA14.Signal=SYS_SWCLK
PA2.GPIO_Label=IsenseIn
PA2.Signal=ADC_IN2
PA3.GPIO_Label=VsenseOut
PA3.Signal=ADC_IN3
PA4.GPIO_Label=IsenseOut
PA4.Signal=ADC_IN4
PA5.GPIO_Label=NTC100K
PA5.Signal=ADC_IN5
PA7.GPIO_Label=boostLOWside
PA7.Signal=TIM1_CH1N
PA8.GPIO_Label=boostHIGHside
PA8.Signal=S_TIM1_CH1
PA9.GPIO_Label=buckHIGHside
PA9.Signal=S_TIM1_CH2
PB0.GPIO_Label=buckLOWside
PB0.Signal=TIM1_CH2N
PB10.Signal=I2C2_SCL
PB11.Signal=I2C2_SDA
PB3.Signal=SPI1_SCK
PB4.Signal=SPI1_MISO
PB5.Signal=SPI1_MOSI
PC10.GPIO_Label=LED
PC10.Signal=GPIO_Output
PC13.GPIO_Label=usbDetect
PC13.Signal=GPIO_Input
PC4.Signal=USART3_TX
PC5.Signal=USART3_RX
PC8.GPIO_Label=fanControllPin
PC8.Signal=S_TIM3_CH3
PD2.GPIO_Label=chipSelect
PD2.Signal=GPIO_Output

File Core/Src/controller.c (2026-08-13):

/**
  ******************************************************************************
  * @file           : controller.c
  * @brief          : Unified Override Control (Min-Selector) implementation.
  ******************************************************************************
  */

#include "controller.h"
#include "system_config.h"
#include "sensors.h"
#include "power.h"
#include "mppt.h"
#include "settings.h"
#include "comms.h"
#include "main.h"
#ifndef NATIVE_TEST
#include "stm32f0xx_hal.h"
#endif
#include <stdio.h>
#include <stdlib.h>

/* Private variables (Encapsulation) */
static SystemState_t currentState = STATE_IDLE;
static FaultReason_t currentFaultReason = FAULT_REASON_NONE;
static SoftLimit_t activeSoftLimit = LIMIT_NONE;
static uint32_t lastMPPTTick = 0;
static uint32_t lastSweepTick = 0;
static uint32_t lastSweepStepTick = 0;
static uint32_t lastTelemetryTick = 0;

/* High-resolution duty cycle accumulator (Velocity PI integral) */
static int64_t globalDutyIntegral = 0;
static int32_t targetDuty_ticks = 0;

/* Control Gains (Scaled for 1ms task) */
#define GAIN_KP 5
#define GAIN_KI 2

/* Velocity PI storage for derivative terms */
static int32_t lastVout = 0;
static int32_t lastIout = 0;

static uint8_t faultCounter = 0;
#define FAULT_THRESHOLD_FRAMES 3

static uint32_t softLimitHoldTimer = 0;
#define SOFT_LIMIT_HOLD_TIME_MS 100
#define SWEEP_STEP_INTERVAL_MS 20
#define FAULT_RECOVERY_DELAY_MS 5000

static uint32_t faultStateEntryTick = 0;

/* Fault Blink Logic */
static uint32_t lastFaultBlinkTick = 0;
static uint8_t blinkPhase = 0;
static uint8_t blinkCount = 0;

static void handleFaultBlink(FaultReason_t reason) {
    uint32_t currentTick = HAL_GetTick();
    uint8_t targetBlinks = 0;
    
    // Define blink codes based on fault reason
    switch (reason) {
        case FAULT_REASON_INPUT_OV:  targetBlinks = 1; break;
        case FAULT_REASON_INPUT_UV:  targetBlinks = 2; break;
        case FAULT_REASON_INPUT_OC:  targetBlinks = 3; break;
        case FAULT_REASON_OUTPUT_OV: targetBlinks = 4; break;
        case FAULT_REASON_OUTPUT_OC: targetBlinks = 5; break;
        case FAULT_REASON_BACKFLOW:  targetBlinks = 6; break;
        case FAULT_REASON_OVERTEMP:  targetBlinks = 7; break;
        default:                     targetBlinks = 0; break;
    }

    if (targetBlinks == 0) {
        HAL_GPIO_WritePin(LED_GPIO_Port, LED_Pin, GPIO_PIN_RESET);
        return;
    }

    // Blink timing: 200ms ON, 200ms OFF, 1000ms pause between cycles
    uint32_t elapsed = currentTick - lastFaultBlinkTick;

    if (blinkPhase == 0) { // Active blinking phase
        if (elapsed >= 200) {
            lastFaultBlinkTick = currentTick;
            HAL_GPIO_TogglePin(LED_GPIO_Port, LED_Pin);
            
            // If we just toggled to OFF (GPIO_PIN_RESET)
            if (HAL_GPIO_ReadPin(LED_GPIO_Port, LED_Pin) == GPIO_PIN_RESET) {
                blinkCount++;
                if (blinkCount >= targetBlinks) {
                    blinkPhase = 1; // Start pause phase
                    blinkCount = 0;
                }
            }
        }
    } else { // Pause phase
        if (elapsed >= 1000) {
            lastFaultBlinkTick = currentTick;
            blinkPhase = 0;
        }
    }
}

/* Internal State Transition Logic */
static void transitionTo(SystemState_t newState) {
    if (currentState == newState) return;
    
    // State Exit Actions
    if (currentState == STATE_FAULT || currentState == STATE_IDLE) {
        if (newState != STATE_FAULT && newState != STATE_IDLE) {
            const Measurements_t *m = SENSORS_GetMeasurements();
            targetDuty_ticks = POWER_CalculateVoltageMatchDuty(m->voltageIn_mV, m->voltageOut_mV);
            POWER_Start();
        }
    }

    // State Entry Actions
    switch (newState) {
        case STATE_SWEEPING:
            MPPT_ResetSweep(targetDuty_ticks);
            activeSoftLimit = LIMIT_SWEEPING;
            lastSweepStepTick = HAL_GetTick();
            break;
        case STATE_ACTIVE:
            globalDutyIntegral = (int64_t)targetDuty_ticks * 1000;
            lastVout = SENSORS_GetMeasurements()->voltageOut_mV;
            lastIout = SENSORS_GetMeasurements()->currentOut_mA;
            MPPT_StartTracking(SENSORS_GetMeasurements());
            activeSoftLimit = LIMIT_NONE;
            break;
        case STATE_IDLE:
            POWER_Shutdown();
            currentFaultReason = FAULT_REASON_NONE;
            faultCounter = 0;
            activeSoftLimit = LIMIT_NONE;
            HAL_GPIO_WritePin(LED_GPIO_Port, LED_Pin, GPIO_PIN_RESET);
            break;
        case STATE_FAULT:
            POWER_Shutdown();
            activeSoftLimit = LIMIT_NONE;
            lastFaultBlinkTick = HAL_GetTick();
            faultStateEntryTick = HAL_GetTick();
            blinkPhase = 0;
            blinkCount = 0;
            break;
        default:
            break;
    }
    
    printf("STATE: %s -> %s\n", CONTROLLER_GetStateString(), 
           (newState == STATE_IDLE) ? "IDLE" :
           (newState == STATE_SWEEPING) ? "SWEEPING" :
           (newState == STATE_ACTIVE) ? "ACTIVE" :
           (newState == STATE_FAULT) ? "FAULT" : "RECOVERY");
           
    currentState = newState;
}

void CONTROLLER_Init(void) {
    currentState = STATE_IDLE;
    currentFaultReason = FAULT_REASON_NONE;
    activeSoftLimit = LIMIT_NONE;
    lastMPPTTick = 0;
    lastSweepTick = 0;
    lastTelemetryTick = 0;
    globalDutyIntegral = 0;
    targetDuty_ticks = 0;
    lastVout = 0;
    lastIout = 0;
}
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

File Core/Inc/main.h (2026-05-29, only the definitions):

#define GPIO_PIN_RESET 0
#define GPIO_PIN_SET   1
#define GPIO_PIN_0     0
#define GPIO_PIN_1     1
#define GPIO_PIN_2     2
#define GPIO_PIN_3     3
#define GPIO_PIN_4     4
#define GPIO_PIN_5     5
#define GPIO_PIN_6     6
#define GPIO_PIN_7     7
#define GPIO_PIN_8     8
#define GPIO_PIN_9     9
#define GPIO_PIN_10    10
#define GPIO_PIN_11    11
#define GPIO_PIN_12    12
#define GPIO_PIN_13    13
#define GPIO_PIN_14    14
#define GPIO_PIN_15    15
#define GPIOA          ((GPIO_TypeDef)0)
#define GPIOB          ((GPIO_TypeDef)1)
#define GPIOC          ((GPIO_TypeDef)2)
#define GPIOD          ((GPIO_TypeDef)3)
#define GPIOF          ((GPIO_TypeDef)4)
#define usbDetect_Pin GPIO_PIN_13
#define usbDetect_GPIO_Port GPIOC
#define VsenseIn_Pin GPIO_PIN_1
#define VsenseIn_GPIO_Port GPIOA
#define IsenseIn_Pin GPIO_PIN_2
#define IsenseIn_GPIO_Port GPIOA
#define VsenseOut_Pin GPIO_PIN_3
#define VsenseOut_GPIO_Port GPIOA
#define IsenseOut_Pin GPIO_PIN_4
#define IsenseOut_GPIO_Port GPIOA
#define NTC100K_Pin GPIO_PIN_5
#define NTC100K_GPIO_Port GPIOA
#define boostLOWside_Pin GPIO_PIN_7
#define boostLOWside_GPIO_Port GPIOA
#define buckLOWside_Pin GPIO_PIN_0
#define buckLOWside_GPIO_Port GPIOB
#define fanControllPin_Pin GPIO_PIN_8
#define fanControllPin_GPIO_Port GPIOC
#define boostHIGHside_Pin GPIO_PIN_8
#define boostHIGHside_GPIO_Port GPIOA
#define buckHIGHside_Pin GPIO_PIN_9
#define buckHIGHside_GPIO_Port GPIOA
#define LED_Pin GPIO_PIN_10
#define LED_GPIO_Port GPIOC
#define chipSelect_Pin GPIO_PIN_2
#define chipSelect_GPIO_Port GPIOD
#define LCD_RST_Pin GPIO_PIN_12
#define LCD_RST_GPIO_Port GPIOB
#define LCD_DC_Pin GPIO_PIN_13
#define LCD_DC_GPIO_Port GPIOB
#define LCD_CE_Pin GPIO_PIN_14
#define LCD_CE_GPIO_Port GPIOB

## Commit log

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2026-05-17 Implement Ping-Pong ADC buffering and safety improvements
    - Implemented Ping-Pong (double) buffering for ADC DMA processing.
    - Added division-by-zero protection in telemetry and duty cycle calculations.
    - Added output constraints to PID controller to prevent integral windup.
    - Fixed platformio.ini monitor_port for Linux compatibility.
    - Updated setup_cubemx_env_auto.py to allow PlatformIO HAL headers.
    - Added comprehensive GEMINI.md instructional context.
    [main.c, setup_cubemx_env_auto.py]
2026-05-17 Convert entire codebase to Semantic Fixed-Point math
    - Replaced all floating-point math with 32-bit and 64-bit integer arithmetic.
    - Renamed variables to include semantic units (e.g., voltageIn_mV, currentIn_mA, powerIn_uW).
    - Refactored readSensors and calibrateSensors to use efficient integer scaling.
    - Refactored PID and MPPT controllers to use dithered timer ticks directly.
    - Updated telemetry printf strings to use integer format specifiers.
    - Updated GEMINI.md to reflect new architecture and conventions.
    - Improved performance on Cortex-M0 by eliminating software floating-point overhead.
    [main.c]
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2026-05-17 Finalize DFU auto-reset and memory preservation logic
    - Implemented .noinit section in linker script to protect dfu_magic flag.
    - Refactored DFU jump logic to use volatile dfu_magic in .noinit section.
    - Optimized DFU jump sequence with NVIC/SysTick clearing and peripheral de-init.
    - Added resume.sh to .gitignore.
    - Updated GEMINI.md and notes.txt with latest project architecture and DFU findings.
    [main.c]
2026-05-17 Revert "Finalize DFU auto-reset and memory preservation logic"
    This reverts commit 13746b93ea540ae97f24eaf1bad5cc2ae2c4f8fc.
    [main.c]
2026-05-17 Hardware verification complete: MPPT sweep and Boost mode confirmed
    - Restored sweep interval to 300s after successful 30s testing.
    - Fixed efficiency telemetry scaling and printf formats.
    - Verified stable fixed-point operation under 28W load.
    - Confirmed Buck-to-Boost transition is functional and precise.
    [main.c]
2026-05-17 Finalized stable firmware with Supply-Aware MPPT Sweep
    - Implemented 'Supply-Aware Sweep' to gracefully terminate scans when input voltage sags below 14V.
    - Restored production sweep interval to 300s.
    - Verified stable Buck and Boost operation on live hardware.
    - Confirmed precision fixed-point math and double-buffered ADC sampling.
    [main.c]
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2026-05-18 refactor: modularize codebase and implement unified state machine
    - Decomposed main.c into specialized modules (Sensors, Power, MPPT, Controller, Comms, Settings).
    - Implemented a unified system state machine with explicit transitions.
    - Added real-time system state display to the Web UI dashboard.
    - Standardized on Embedded C patterns and encapsulated internal states.
    - Switched to HAL_GetTick based timing for improved stability.
    [comms.c, controller.c, main.c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]
2026-05-18 feat: implement descriptive fault handling and hardware safety architecture
    - Refactored fault handling to separate operational regulation from hardware safety limits.
    - Added descriptive fault reasons: INPUT_OV, INPUT_UV, INPUT_OC, OUTPUT_OV, OUTPUT_OC, BACKFLOW, OVERTEMP.
    - Implemented global Brownout Protection (12.5V hard limit, 14V soft floor) across all modes (CV/CC/MPPT).
    - Added CMD:RESET_FAULT serial command and interactive Reset button to Web Dashboard.
    - Updated Web Dashboard to display descriptive fault reasons and dynamic recovery controls.
    - Configured platformio.ini for Black Magic Probe (BMP) upload protocol.
    [comms.c, controller.c, system_config.h]
2026-05-18 fix: resolve stale PID setpoints and improve regulation smoothness
    - Updated CV and CC PID controllers to refresh setpoints from active limits in every cycle.
    - Reduced regulation hysteresis to 100mV/50mA to prevent excessive state flapping.
    - Added integral gain and tuned PID parameters for zero steady-state error and smoother transitions.
    - Included active V/I limits in telemetry for better diagnostic visibility.
    - Updated Web Dashboard to reflect real-time active limits in the input fields.
    [comms.c, controller.c, system_config.h]
2026-05-18 fix: resolve USB lockup, implement safe EEPROM defaults, and enhance UI
    - Added timeout to USB TX loop in _write() to prevent boot lockup without host.
    - Implemented EEPROM signature check to ensure safe defaults on first flash.
    - Forced PWM shutdown during EEPROM saves to prevent controller/hardware crashes.
    - Added CMD:GET_LIMITS to synchronize dashboard with firmware state on connect.
    - Updated Dashboard UI to format telemetry in V/A/W and auto-fetch device limits.
    - Removed obsolete operational inputs for hardcoded safety limits.
    [comms.c, main.c]
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2026-05-18 fix: eliminate regulation ripple by correcting PID math and tuning gains
    - Corrected mathematical error in POWER_PID_Compute: switched to proper Velocity PI form to prevent double-integration instability.
    - Retuned PID gains (Kp=10, Ki=2) for stable 200Hz response.
    - Implemented limit-aware P&O logic: MPPT algorithm now respects voltage/current boundaries to prevent aggressive state transitions.
    - Increased CV/CC exit hysteresis to 500mV to ensure state stability.
    [controller.c, power.c, system_config.h]
2026-05-18 fix: eliminate USB connection requirement and prevent headless crashes
    - Added NULL pointer check in CDC_Transmit_FS to prevent HardFault when USB is disconnected.
    - Reduced iteration timeout in _write loop from 1,000,000 to 10,000 to ensure high-rate regulation continues smoothly even if USB host buffers are full.
    - Verified that the board now boots and regulates autonomously without a connected serial interface.
    [main.c]
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2026-05-18 perf: optimize MPPT tracking speed and accuracy
    - Slowed down global power sweep (SWEEP_STEP_SIZE_TICKS=8) to allow hardware settling and prevent overshooting the MPP baseline.
    - Implemented P&O accumulation logic: now tracks small power changes over multiple cycles, preventing the algorithm from 'walking' away from the MPP on gentle slopes.
    - Added MPPT_StartTracking to re-initialize tracking immediately after a sweep, ensuring a fast and clean transition into P&O mode.
    - Verified rock-solid input voltage stability at the MPP with no 2V offset.
    [controller.c, system_config.h]
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2026-05-18 fix: unify limit keys and ensure consistent unit conversion on dashboard
    - Unified all device limit JSON keys to Vmax_limit, Vmin_limit, and Imax_limit across telemetry and fetch responses.
    - Fixed unit conversion bug in app.js: both telemetry and fetch routines now correctly divide mV/mA by 1000 for standard unit display (V/A).
    - Enabled real-time syncing of dashboard inputs with firmware state via live telemetry, while preventing cursor-jump by checking for active focus.
    [comms.c]
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2026-05-18 feat: implement autonomous brownout recovery logic
    - Updated STATE_FAULT handling to automatically transition back to STATE_IDLE when an INPUT_UNDERVOLTAGE fault is resolved (Vin > 14V).
    - This allows the system to resume charging autonomously without manual dashboard interaction after a temporary source collapse.
    - Verified seamless recovery and restart of the MPPT sweep during testing.
    [controller.c, power.c]
2026-05-18 fix: implement EMA software filtering for current and voltage measurements
    - Added an Exponential Moving Average (EMA) filter to the SENSORS_Process loop.
    - Current measurements now use a shift-based filter (alpha=0.125) to eliminate high-frequency noise and jitter.
    - Voltage measurements use a lighter filter (alpha=0.25) to provide smoother telemetry without introducing lag.
    - This significantly improves the stability of the telemetry display and the reliability of the CC regulation loop.
    [sensors.c]
2026-05-18 chore: remove redundant limit fields and unused variable from telemetry
    - Removed Vmax_limit, Vmin_limit, and Imax_limit from the periodic telemetry JSON output.
    - Removed the unused 'limits' variable in COMMS_SendTelemetry to fix compilation error.
    - Streamlined serial bandwidth by focusing telemetry on real-time measurements.
    [comms.c]
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2026-05-19 fix(power): correct pass-through duty cycle for calibration
    Modified calibration override to use 100% duty cycle (timer period) instead of max boost duty cycle. This prevents the input stage from switching and shorting the inductor during current calibration.
    [controller.c]
2026-05-19 feat(sensors): apply EMA filtering to RAW ADC values
    Implemented an Exponential Moving Average (EMA) filter for the raw ADC sums. This provides smoother data for the calibration wizard and reduces noise in the recorded calibration points.
    [sensors.c]
2026-05-19 refactor(sensors): consolidate EMA filtering to RAW ADC level
    Removed redundant mV-level filtering and replaced it with a single-stage high-precision EMA filter at the RAW ADC stage. All derived measurements (telemetry, dashboard raw values, and control loop) now use the same filtered baseline.
    [sensors.c]
2026-05-19 fix(sensors): implement high-precision 10-bit fixed-point EMA filter
    Refactored the sensor filtering to use a 10-bit fixed-point shift (scale by 1024). This preserves sub-bit oversampling resolution during the EMA calculation, providing significantly more accurate filtered values for both the dashboard and the control loop.
    [sensors.c]
2026-05-19 fix(sensors): dual-stage EMA filtering for speed and stability
    Implemented a dual-stage EMA filter: a FAST filter (alpha 0.5) for the MPPT control loop to eliminate phase lag-induced oscillation, and a SLOW filter (alpha 0.0625) for the dashboard calibration UI. Both use high-precision 10-bit fixed-point math.
    [sensors.c]
2026-05-19 fix(power): refactor PID to Derivative-on-Input for smooth setpoint tracking
    Refactored the Velocity PID algorithm to use the 'Derivative-on-Input' form. This handles dashboard setpoint changes gracefully by avoiding proportional kick and ensuring immediate integral response. Also reduced CV/CC hysteresis to improve responsiveness to small limit adjustments.
    [controller.c, power.c, system_config.h]
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2026-05-19 feat(mppt): implement high-performance Adaptive VSS P&O
    Upgraded the MPPT algorithm to Variable Step Size (VSS) using the |dP/dV| slope calculation. Reduced the MPPT interval to 20ms. This achieves significantly faster tracking during transients while eliminating steady-state oscillation. Added safety bounds and voltage deadband for noise immunity.
    [system_config.h]
2026-05-19 tune(mppt): stabilize VSS P&O parameters
    Reduced scaling factor (N=4), minimum step (1 tick), and power threshold (10mW) to eliminate steady-state oscillation. Increased interval to 30ms to ensure inductor settling between fast perturbations.
    [system_config.h]
2026-05-19 tune(mppt): dampen VSS for stable sources and add step telemetry
    Reduced VSS_N_FACTOR to 1 and VSS_MAX_STEP to 8 to prevent over-corrections on low-impedance power supplies. Added 'mppt_step' to serial telemetry for real-time algorithm monitoring.
    [comms.c, system_config.h]
2026-05-19 tune(mppt): loop iteration 2 - increase VSS sensitivity
    Increased N_FACTOR to 2, lowered deadband to 20mV, and reduced interval to 25ms. Aiming for faster convergence without re-introducing oscillation.
    [system_config.h]
2026-05-19 tune(mppt): loop iteration 3 - optimize for faster tracking
    Increased N_FACTOR to 3 and MAX_STEP to 20. Reduced interval to 20ms. This should provide much faster response to changing conditions while maintaining micro-step stability at the peak.
    [system_config.h]
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2026-05-19 tune(mppt): loop iteration 5 - ultra-stability
    Limited MAX_STEP to 10 and increased interval to 30ms. Lowered POWER_THRESHOLD_UW to 5mW. This configuration prioritizes rock-solid stability and precision over raw tracking speed.
    [system_config.h]
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2026-05-19 feat(mppt): implement high-stability 100ms Adaptive P&O
    Optimized the MPPT algorithm for high-voltage stability. Features 100ms settling time, Alpha 0.25 EMA filtering, and high-gain search scaling. Successfully verified stable tracking at 30W+ peak on 60V lab supply with <0.5% ripple.
    [sensors.c, system_config.h]
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2026-05-19 Harden firmware: implement fault hysteresis, filter hot-start, and PID transition smoothing.
    - Added 3-frame temporal hysteresis to prevent nuisance fault trips from EMI spikes.
    - Enhanced EMA filter initialization to 'jam-load' values on first valid ADC sample.
    - Cleared PID derivative history on state transitions to eliminate 'derivative kick'.
    [controller.c, sensors.c]
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2026-05-19 refactor: revert to fixed-step MPPT, purge VSS architecture, and upgrade tuner script
    [comms.c, main.c, sensors.c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]
2026-05-19 feat: implement dead-band escape strategy and refactor reset logic
    - Decoupled logical duty cycle from hardware clamping in power.c.
    - Added CONTROLLER_Reset() for unified system reset to IDLE.
    - Fixed native environment build and updated outdated MPPT unit tests.
    - Updated GEMINI.md with new architectural details.
    - Added tuning_logs to .gitignore.
    [comms.c, controller.c, power.c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]
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2026-05-20 Revert "feat: implement robust USB DFU trigger and jump mechanism"
    This reverts commit e967b7dd93cc7356b9f8e956725afbb2860c299a.
    [comms.c, main.c, main.h]
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2026-05-21 feat: refactor operational logic with unified Min-Selector and active limit tracking
    - Implemented Min-Selector override control in controller.c for unified CV/CC/MPPT logic.
    - Added SoftLimit_t tracking for high-fidelity status reporting (ACTIVE_CV, ACTIVE_CC, etc.).
    - Renamed DeviceLimits_t fields to flow-centric names (vOutMax, iOutMax, iOutMin).
    - Unified reverse-current logic for both MPPT backflow protection and E-Bike regen.
    - Added comprehensive unit test suite in test/test_controller/ verifying all limits and tagging.
    - Fixed state leakage in unit tests and refined tagging priority logic.
    [comms.c, controller.c, test_controller.c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]
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2026-05-21 feat: complete full-stack integration of Input Voltage Max limit
    - Implemented LIMIT_V_IN_MAX (Reverse CV) in controller.c Min-Selector.
    - Added ACTIVE_VIN_LIMIT status reporting to firmware and dashboard.
    - Added Input Voltage Limit control field to dashboard UI.
    - Implemented CMD:SET_VIN_MAX in comms.c for remote configuration.
    - Synchronized all dashboard data fields (Vmax, Vmin, VinMax, Imax, Imin) with firmware.
    [comms.c, controller.c]
2026-05-21 fix: implement 'Hard-Zero' safety mechanism in power.c
    - Added hardware-level shutdown (MOE disable) when duty cycle is <2%.
    - Prevents synchronous Low-Side MOSFETs from shorting the battery to ground at 0% duty.
    - Ensures all regulation limits (including Reverse CV) have a safe 'High-Impedance' state to pull back to.
    [power.c]
2026-05-29 fix(control): stabilize CC/CV transitions and fix calibration bypass
    - Reduced GAIN_KP to 5 for smoother PI regulation
    - Added 100ms state-hold hysteresis to activeSoftLimit reporting to prevent dashboard UI flickering
    - Modified calibration entry to explicitly call POWER_Start() to clear MOE dead-states
    - Prevented FAULT state transitions during active calibration
    - Fixed dashboard limit_mode synchronization on connect
    - Fixed comms buffer contamination from trailing carriage returns
    [comms.c, controller.c]
2026-05-29 fix: resolve battery backflow fault and sweep overvoltage
    - Pre-calculate voltage-matched initial duty cycle upon startup to
    prevent 0% duty cycles from causing massive reverse current when
    a battery is connected to the output.
    - Add soft limit checks (vOutMax, iOutMax, iOutMin, vInMax) to the
    MPPT sweep algorithm to prevent the power stage from driving into
    hardware faults when sweeping without a load.
    [controller.c, power.c]
2026-05-29 feat: implement visual LED heartbeat and fault blink codes
    - Add slow heartbeat (100ms ON / 1900ms OFF) when STATE_ACTIVE is healthy.
    - Implement blink codes for diagnostics when in STATE_FAULT:
    - 1 Pulse: Input Over-voltage
    - 2 Pulses: Input Under-voltage
    - 3 Pulses: Input Over-current
    - 4 Pulses: Output Over-voltage
    - 5 Pulses: Output Over-current
    - 6 Pulses: Backflow Fault
    - 7 Pulses: Over-temperature
    - Ensure LED is reset during IDLE and state transitions.
    [controller.c]
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2026-05-29 fix: implement fault auto-recovery and fix CV stall under no-load
    - Add 5-second auto-recovery timer to STATE_FAULT. System will now
    automatically retry after backflow or overvoltage transients.
    - Implement 'No-Load Pressure' in MPPT loop. If output current is
    low (<100mA) and the algorithm stalls, force a slow voltage
    increase until the soft CV limit is reached.
    - Fixes issue where battery reconnection triggered backflow due
    to the controller stalling at a low voltage when battery was gone.
    [controller.c]
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2026-08-12 fix: correct reverse-flow control sign bugs and unify backflow protection
    Root-causes a real hardware failure: testing backflow/reverse mode
    blew up the input side with an overvoltage. Traced to two positive-
    feedback sign bugs in the STATE_ACTIVE min-selector where the Reverse
    CC and Reverse CV constraints decreased duty on violation instead of
    increasing it. Per POWER_CalculateVoltageMatchDuty's own equilibrium-
    duty model (duty is monotonically increasing with Vout/Vin ratio),
    duty below the match point drives reverse current — so decreasing
    duty on a reverse-flow violation actively worsens it, re-triggering
    every control tick until hardware limits are exceeded.
    Also redesigns backflow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
    [comms.c, controller.c, eeprom.c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]
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2026-08-12 Vendor easyeda2kicad component library; rename project files; fix stale part data
    Vendors the 16 easyeda2kicad:* parts (symbols/footprints/3D models) that
    were referenced but never committed, registers them in sym-lib-table and
    a new fp-lib-table, and adds the EASYEDA2KICAD project text variable so
    existing 3D-model paths resolve.
    Also corrects BSC030N08NS5's stale metadata (was pointing at an ElecSuper
    clone, C49108769, instead of the genuine Infineon part, C501507) and
    swaps its footprint to the freshly-fetched one, and fixes STANDARDS.md's
    Hardware Universe table (stale reference designators, stale MOSFET/
    CC6937 LCSC numbers, ~13 previously undocumented parts, wrong library
    path).
    Rena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
    [ProPrj_STM32 MPPT_2024-07-25_15-40-35_2026-05-30.kicad_pcb, buck_boost.kicad_sch, connectors.kicad_sch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]
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2026-08-12 fix: correct diode part data, select L4 inductor, drop DRC/ERC mandate
    Diode inventory (D1-D7): replaced STANDARDS.md's fictional D_BOOT (US1M)
    and D_OFF (1N4148W) rows - never actually placed - with the real,
    schematic-verified parts: SS210 for both the gate-driver bootstrap role
    (D1/D4) and gate-discharge role (D2/D3/D5/D6), and SS510 as the SCT2A25
    switch-node freewheeling diode (D7). Fixes the PCB footprint mismatch on
    D2/D3/D5/D6 (D_SOD-123 -> D_SMA, matching what the schematic already
    specified and SS210 actually needs) and the JLCPCB/PCM_JLCPCB library
    nickname mismatch on UA1/UB1's footprint reference.
    L4 main inductor: replaced FC-SE2822-150M with HCZH-3218-150-M (C53699952)
    in the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
    [buck_boost.kicad_sch, openMPPT_v1.3.kicad_pcb]
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2026-08-12 fix: upsize L2 aux inductor for fault-current headroom
    Replaces APS0650M470A (47uH, Isat 2.62A, DCR 227mOhm) with GXDR1207-470MT
    (FAUKU, C52196367, $0.207, 11735 in stock) for L2, the SCT2A25 10V rail's
    inductor. Same 47uH, but Isat now matches SCT2A25's own 4A peak current
    limit exactly instead of saturating well below it, and DCR drops to
    90mOhm. The original part was sized for the baseline gate-driver/logic
    load (~150-500mA), not for a heavier load (e.g. a fan) that might get
    added to the 10V rail - same underlying reasoning as why D7 stays SS510
    instead of SS210. Applied to both the schematic and PCB (package grew
    from 7.7x6.6mm to 12.5x12.5mm SMD).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
    [openMPPT_v1.3.kicad_pcb, power.kicad_sch]
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2026-08-13 fix(power): bootstrap-safe PWM map + restore 200kHz duty resolution
    v1.3 drops the isolated high-side gate supply for bootstrap caps, which
    only recharge while their leg's low side conducts. The old hardware map
    pinned one leg's high side to literal 100% for the entire duration of
    sustained buck-only or boost-only operation (and both legs at crossover/
    calibration), starving that leg's bootstrap cap indefinitely.
    Rescale the PWM map to reference CEILING_TICKS (MAX_DUTY_CYCLE_TICKS minus
    a ~6% BOOTSTRAP_REFRESH_TICKS reserve) as both the input and output bound,
    not just an output clamp. This guarantees a low-side refresh window every
    cycle in deep buck, deep boost, at crossover, and in calib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
    [power.c, system_config.h]
2026-08-13 test(power): add native coverage for bootstrap-refresh PWM map
    New test/test_power suite exercises the real POWER_PWM_Set/
    POWER_CalculateVoltageMatchDuty logic directly (power.c is
    self-contained once NATIVE_TEST strips its HAL calls, so no mocks
    are needed) and asserts the actual bootstrap-safety guarantee: the
    fixed/non-switching leg never reaches the literal top of the duty
    range across deep buck, deep boost, and the crossover point, and the
    buck/boost handoff lands on a single continuous point rather than a
    plateau.
    Update the three existing suites' POWER_PWM_GetMax mocks from 240*8
    to 240*16 to match the new MAX_DUTY_CYCLE_TICKS after the dither
    depth bump.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
    [test_controller.c, test_ebike.c, test_power.c]
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2026-08-13 fix(power): remove near-passthrough anti-chatter dead-band
    The old isolated-gate-supply code snapped hardwareDuty to a fixed value
    across a band around crossover, to avoid flip-flopping a leg between
    "fully static" (literal 100%, zero switching) and "actively switching".
    That bought a real efficiency win in the old topology, but it also froze
    the physical PWM output across ~4% of the duty range: MPPT would step its
    internal duty accumulator through that band (still recorded via
    currentDutyCycle_ticks, so it wasn't literally stuck) but see zero power
    feedback while doing so, since CH1/CH2 didn't move at all.
    With bootstrap caps, the static/switching distinction the snap protected
    against doe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
    [power.c, test_power.c]
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2026-08-13 fix(hardware): remove D9 (H3V3L06B) TVS diode from power.kicad_sch
    Completes the removal decided in 4070cb0 ("docs: remove D9 (H3V3L06B)
    3.3V TVS, verified it cannot do its job") - that commit documented the
    decision but the schematic instance itself hadn't been deleted yet.
    Removes the D9 symbol instance and its now-orphaned cached library
    symbol definition.
    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
    [power.kicad_sch]
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2026-08-13 hardware: fix L4 footprint's broken 3D model path, sync PCB from schematic
    The L4 footprint (IND-TH_L33.5-W23.0-P12.00_HCZH-3218) had a malformed
    3D model path with a doubled directory segment:
    ${KIPRJMOD}/hardware/KiCad/libraries/... instead of
    ${KIPRJMOD}/libraries/... (KIPRJMOD already resolves to hardware/KiCad/,
    the .kicad_pro's own directory) - so it silently failed to resolve,
    looking like a missing/misaligned 3D model in the viewer rather than an
    outright broken path. Re-saving the footprint in the Footprint Editor
    fixed the path and, as a side effect, upgraded the whole file from the
    legacy (module ...) format to the current (footprint "...") format -
    KiCad does this automatically f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
    [openMPPT_v1.3.kicad_pcb]

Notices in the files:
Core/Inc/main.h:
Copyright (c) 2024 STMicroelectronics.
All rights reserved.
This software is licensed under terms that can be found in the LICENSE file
